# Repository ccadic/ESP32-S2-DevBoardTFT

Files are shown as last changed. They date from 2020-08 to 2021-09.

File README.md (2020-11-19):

# ESP32-S2-DevBoardTFT

BREAKING NEWS !!!!! We started a Crowdsupply campaign because of many requests. You can get a fully assembled product here: https://www.crowdsupply.com/morpheans/morphesp-240
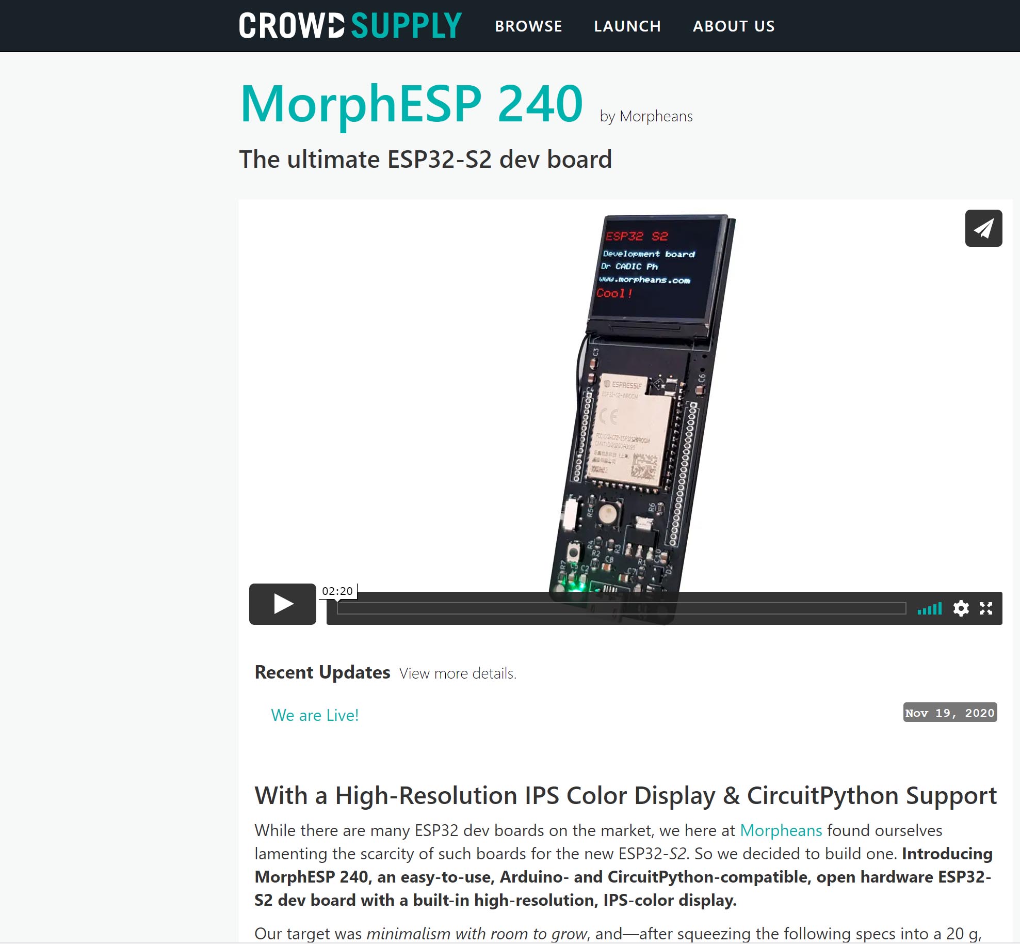
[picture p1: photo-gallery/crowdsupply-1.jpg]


Esp32-S2 dev board with 240x240 IPS display

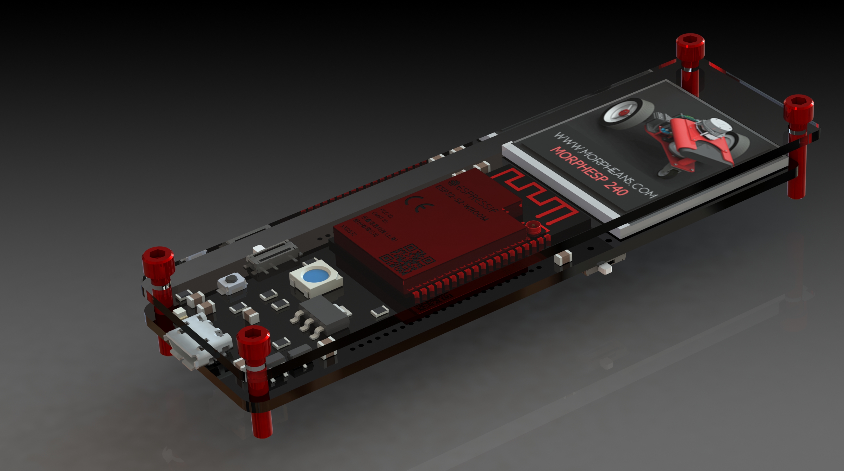
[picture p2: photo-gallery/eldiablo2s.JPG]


A powerfull dev board with the ESPRESSIF™ ESP32-S2®, a high resolution display, a RGB LED, a battery charger and a bunch of GPIOs.

There are many ESP32 board on the market but very few with the new ESP32-S2 which handles USB communications, new cryptography functions. We wanted to have a board with a built in hi-resolution IPS Color Display. After years playing with previous versions of the ESP32, building security devices, text pagers, we just wanted to go one step further and have our opensource circuit.

We wanted to have something minimalistic but expandable so we chose the ESP32 S2 WROOM component , a classic WS2812B RGB LED, a classic 5v to 3.V voltage regulator. 
We wanted something extremely easy to use therefore fully compatible with ARDUINO® IDE plateform.  We also wanted something simple to handle as a first crowdfunding project. 

Features & Specifications

•	Processing:
    o	32-bit esp32 processor operating at 240 MHz
    o	4 MB SPI flash

•	Wireless:
    o	2.4 GHz Wi-Fi - 802.11b/g/n
    o	PCB Antenna

•	Power:
    o	3.3 V LDO regulator
    o	Optimised power path for low-power battery usage
    o	LiPo battery management
    o	Battery pads on the bottom support both JST PH 
    o	Power LEDs

•	Form-factor:
    o	1.27 pinout spacing connector
    o	Breadboard friendly with the dev shield

•	Connectivity:
    o	GPIO broken out to standard pitch headers 1.27 mm
    o	USB + serial/UART for programming
    o	On Board Programmable RGB LED

•	Control:
    o	Arduino IDE compatibility and MicroPython compatibilité
    o	Supports Arduino IDE
    o	Supports Espressif IDF
    o	Thousands of code over the internet

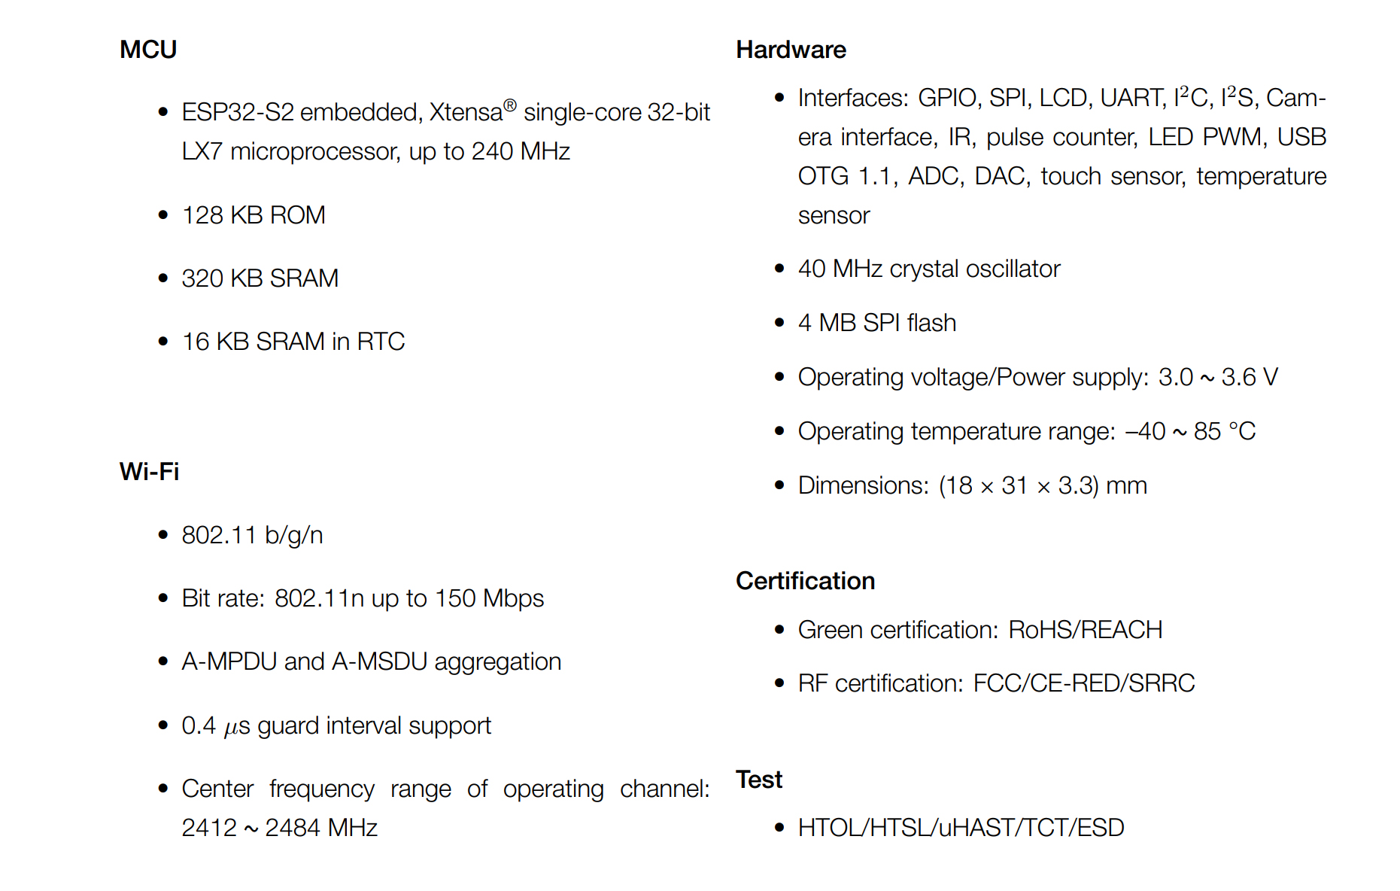
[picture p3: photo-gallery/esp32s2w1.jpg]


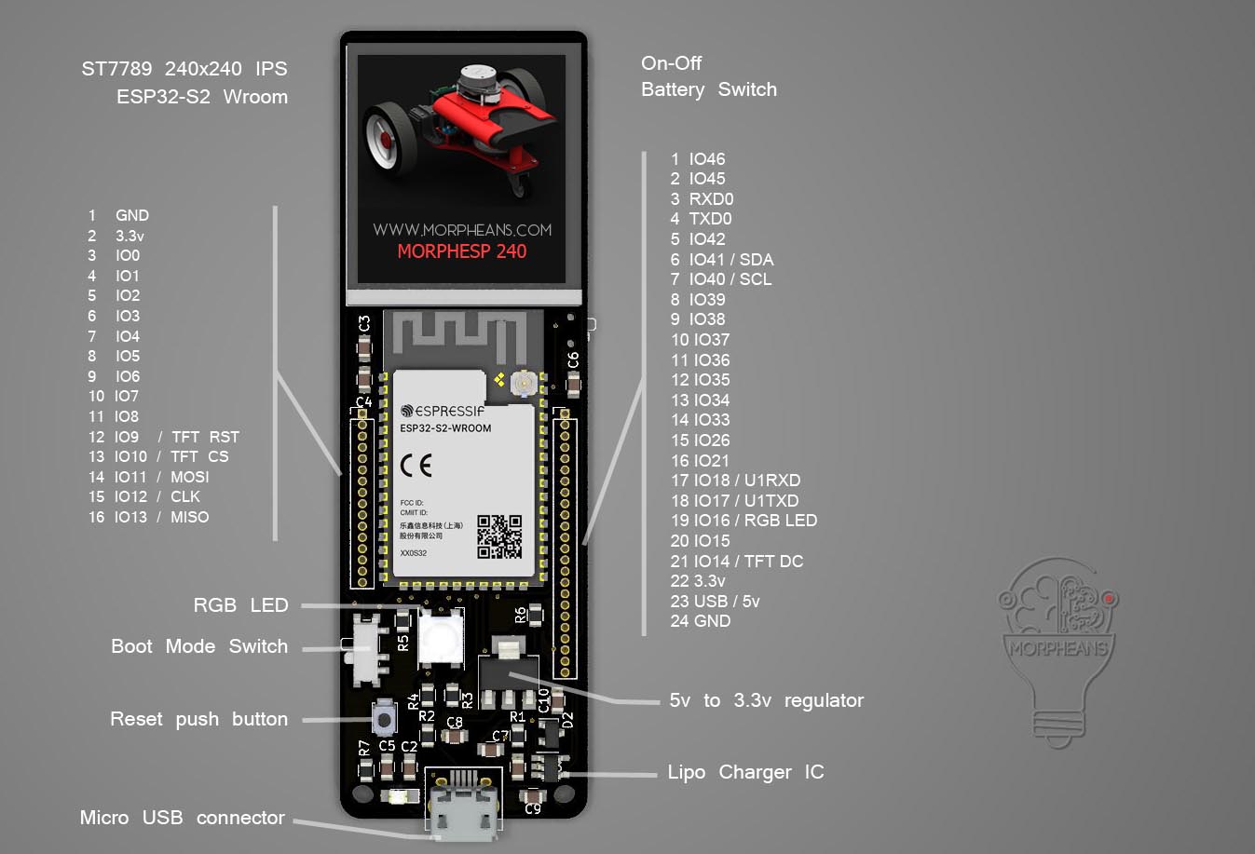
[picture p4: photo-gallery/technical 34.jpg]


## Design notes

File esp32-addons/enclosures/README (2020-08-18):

This dir has all the files if you want to designn, modify or print enclosures for the MORHESP 240
It contains plans, stp, solidworks, STEP files

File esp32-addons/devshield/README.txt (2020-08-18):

(C) 2020 - Dr CADIC Philippe
www.morpheans.com

This is a breadboard friendly development shield for the MORPHESP 240
You get access to all GPIO, grouped connectors (SPI , I2C)...

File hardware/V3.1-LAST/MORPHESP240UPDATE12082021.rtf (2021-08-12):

MORPHESP240
Update

Hi ALL Backers
We would like to thank you all for our first campaign. As this was the first attempt for us, we have learned a lot of things any small team should learn. This was a great experience for the 2 of us.
Almost 90% of you should have received your MORPHESP240 which make us glad. Over the hundreds MORPHESP240 delivered, we have 2 or 4 of you asking for clarification or facing problems (mostly the USB connection and sketch uploads)
The ESP32S2 is new and we chose to have a direct USB connection (morphESP240 does not use a converter such as the CP2104 or CH240G), therefore you need to switch the dev board into boot mode to be able to have it recognized by your ARDUINO IDE interface and OS.
You also have to be careful about the Espressif® Boards Lib you use within ARDUINO IDE. Get sure you have the latest which has the ESP32S2-dev . Please read the READ_FIRST.pdf file you find in the github directory (https://github.com/ccadic/ESP32-S2-DevBoardTFT/tree/master/hardware/V3.1-LAST) . This file gives details on the different steps you have to follow to get a good upload.
We have updated the KICAD sources and schematics. PLease visit : https://github.com/ccadic/ESP32-S2-DevBoardTFT/tree/master/hardware/V3.1-LAST
We also have a couple of requests from Linux users and mac users. The process to upload should not be a lot different byt we admit we have a lower expertise with those systems as the MORPHESP240 has been made and eavily tested under Windows® Please be kind with us if we cannot answer all technical questions about other systems. Most of the time, we ask, and get returns from the linux/mac community of backers who managed. We will regularly update our FAQ should backers raise issues in the future.

Florian & Philippe
Back at work to prepare another fun crowdsupply campaign …. Stay tuned

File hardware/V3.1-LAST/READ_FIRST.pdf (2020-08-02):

ESP32-S2 DEV BOARD , HOW TO START

To upload the sketch you have to select the proper board. See video. https://tutorial.cytron.io/2020/06/25/program-esp32-s2-using-arduino-ide-unofficial/ to understand how to setup arduino IDE. When ARDUINO IDE is set correctly, you can plug the ESP32-S2 dev board to the USB port.

Select the following parameters for the board . You should also select UPLOAD MODE from UART0 to USB CDC

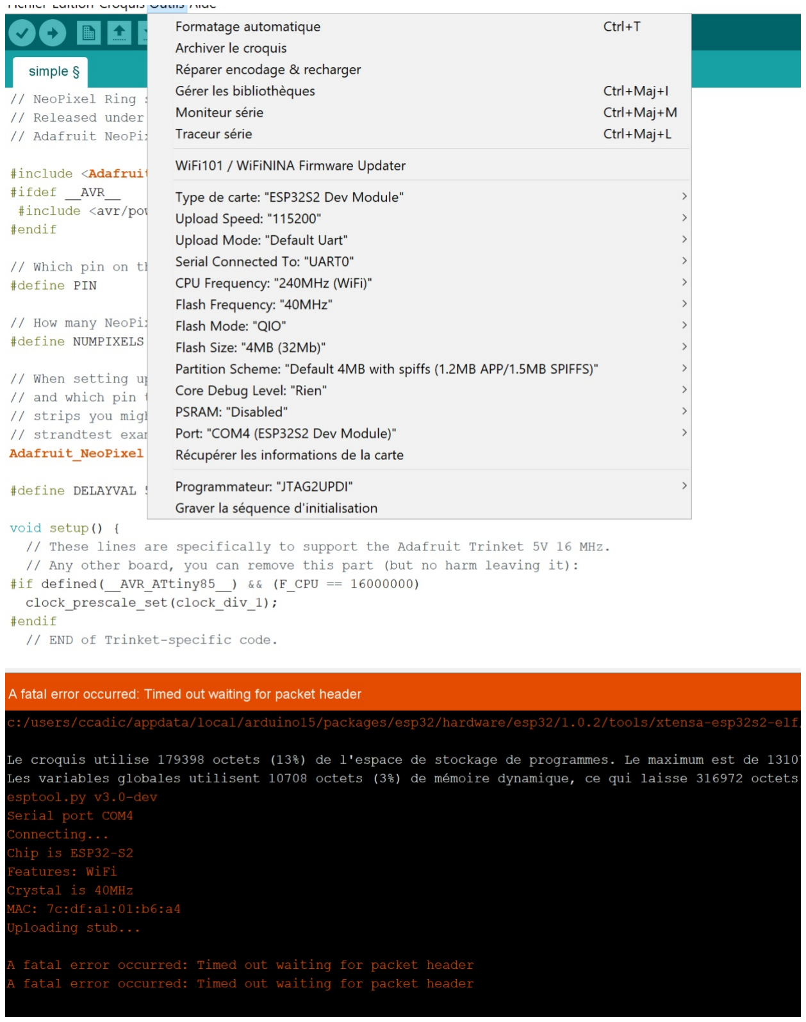
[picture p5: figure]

And select USB UPLOAD MODE to USB CDC

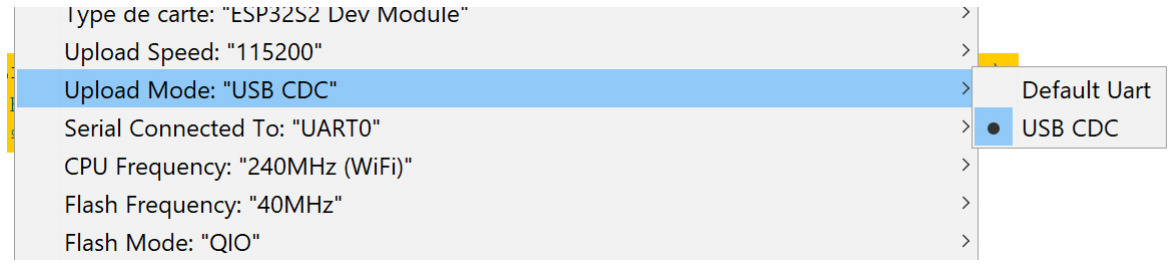
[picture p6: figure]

Put the board in upload mode. For this, put the left button (boot) to the up position and then press the RESET BUTTON (near R7 Resistor). Release the RESET BUTTON and keep BOOT switch in position. The sketch should upload well. Once uploaded , put the BOOT switch to off (Down position) and press RESET again. The ESP32-S2 should now reboot in RUN MODE.

CORRECTION / GERBER 1

The Gerber1 has a small issue you may correct. The TFT DISPLAY RESET has no trace to GPIO12. It is suggested to solder a small wire from PIN 11 of the TFT Display and connect its orther end to GPIO12 of the ESP32 WROOM.

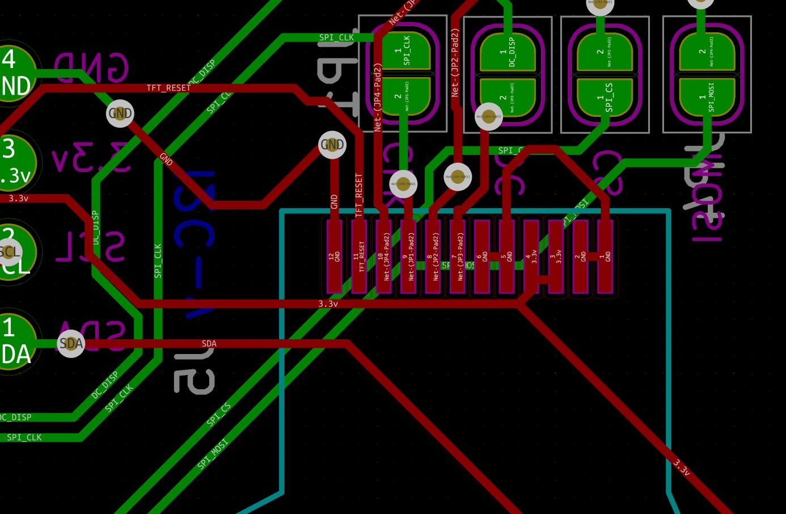
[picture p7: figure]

Gerber 1.2 has corrected this issue.

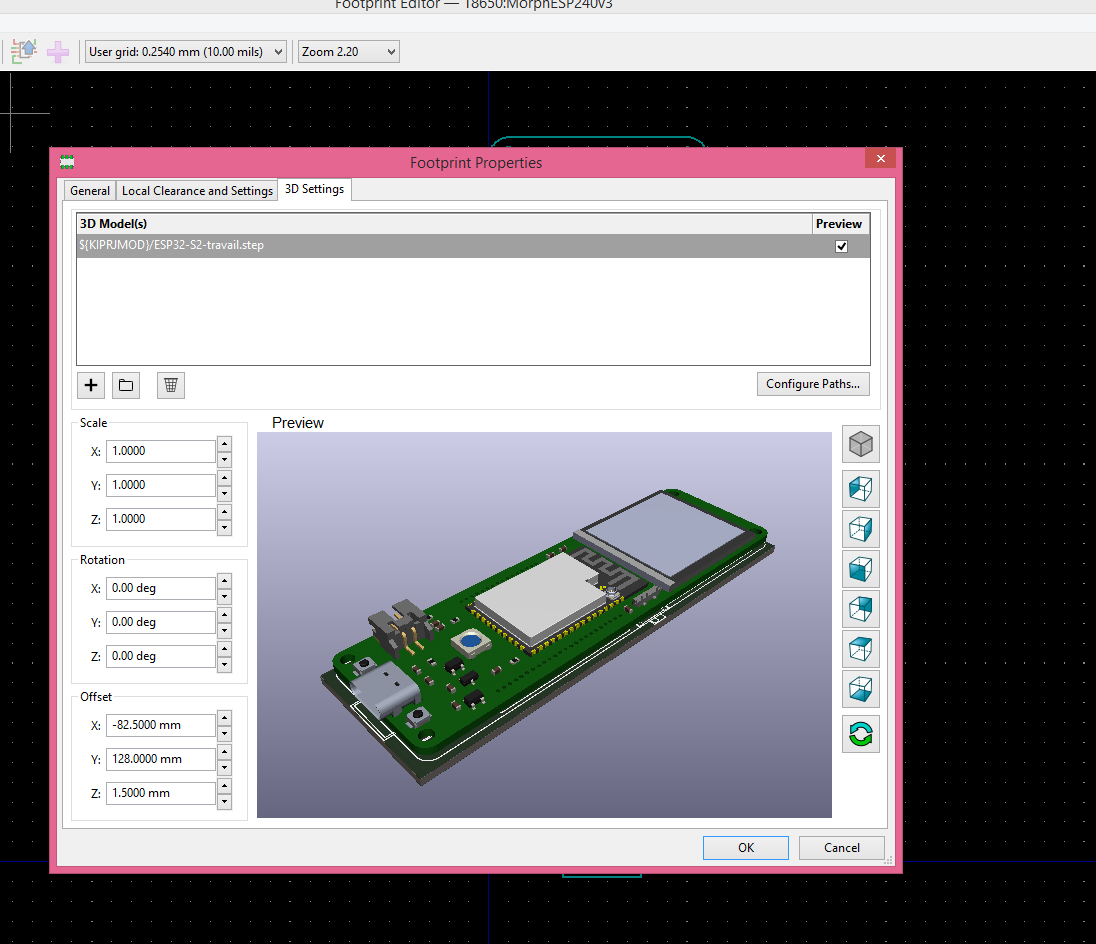
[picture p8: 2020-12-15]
hardware/v3/kicad_footprint/kicad-2.jpg

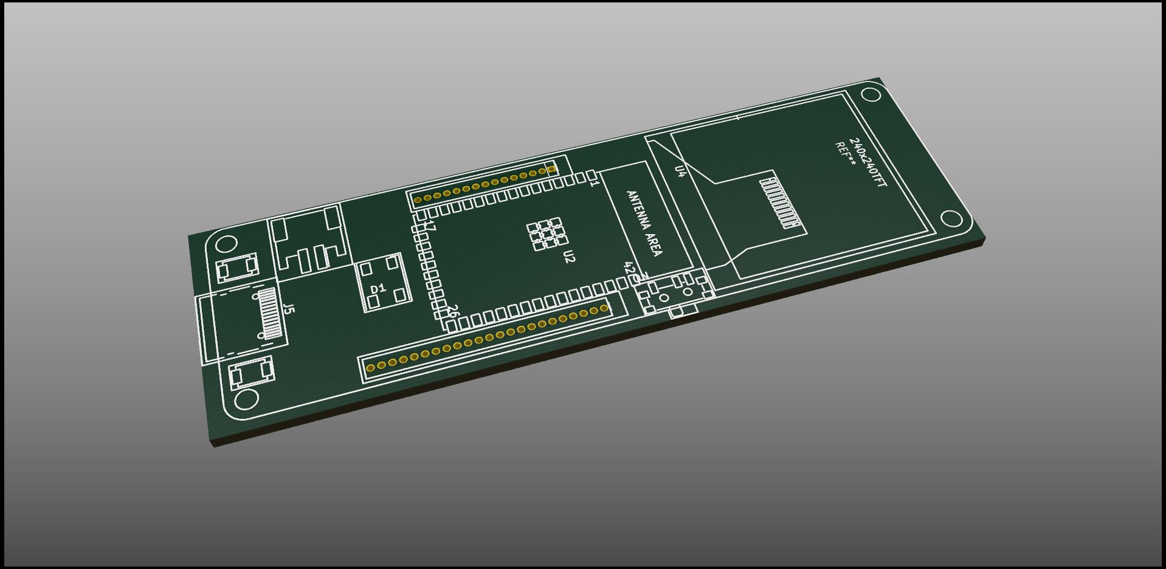
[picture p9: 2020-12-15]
hardware/v3/kicad_footprint/kicadv3fotprint.jpg

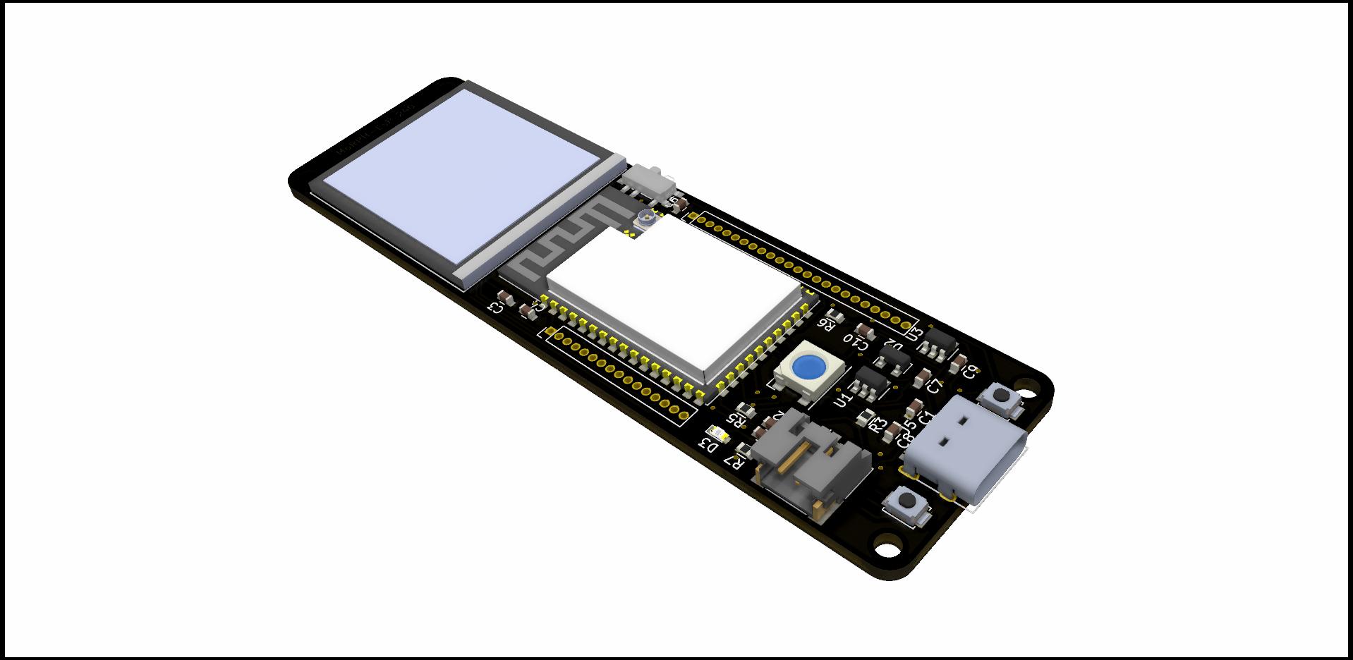
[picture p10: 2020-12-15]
hardware/v3/kicad_footprint/morphESP240v3.jpg

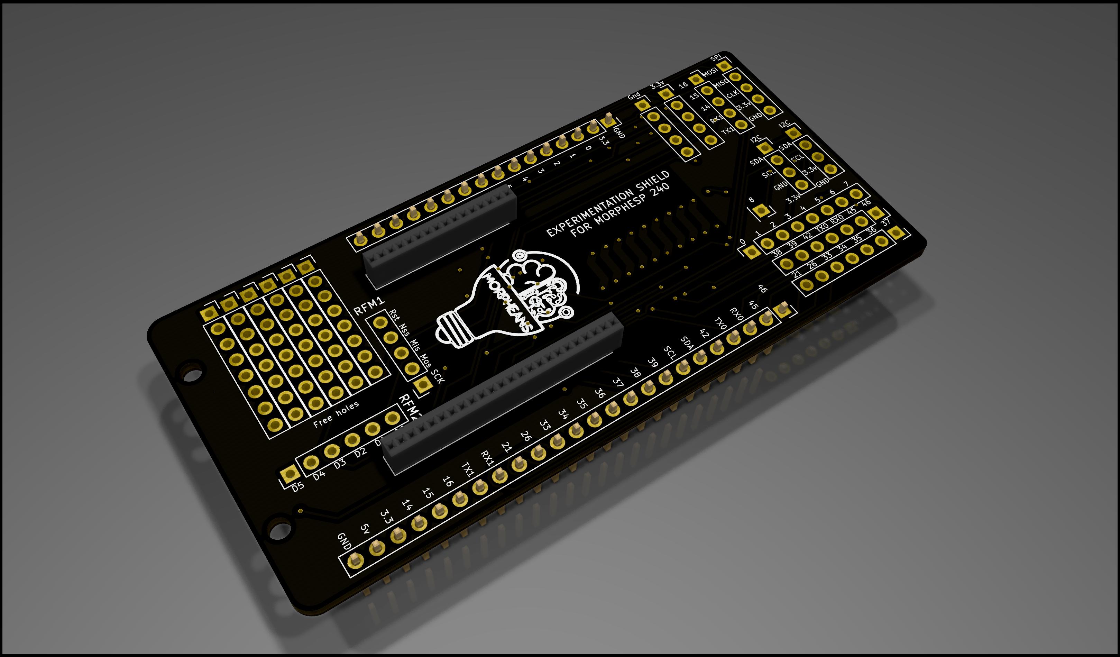
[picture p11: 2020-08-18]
esp32-addons/devshield/images/ESP32-S2-WROOM.jpg

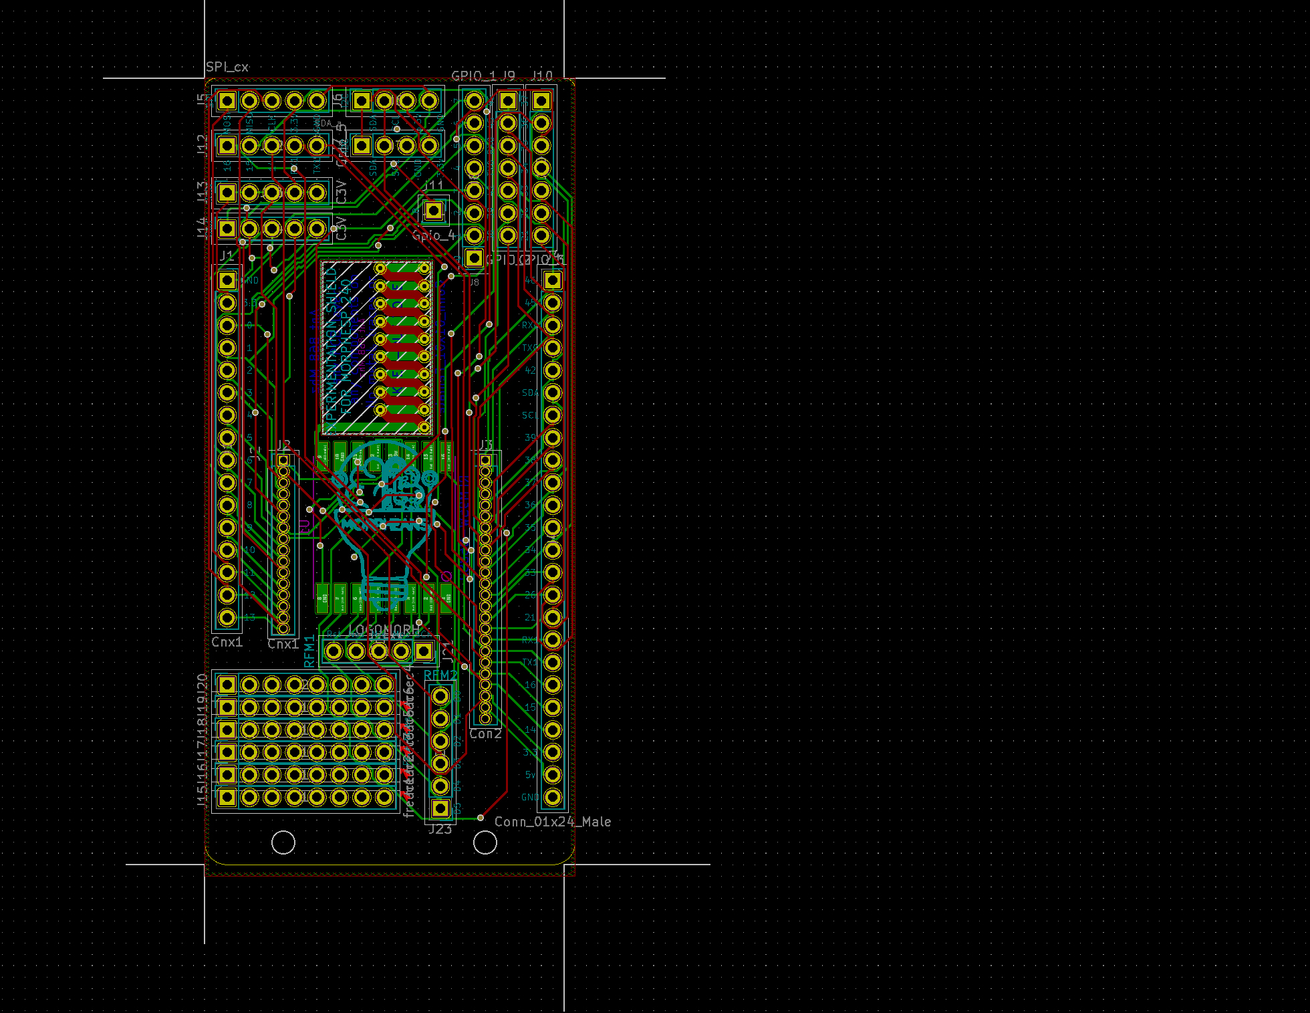
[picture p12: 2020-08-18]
esp32-addons/devshield/images/boardimage.jpg

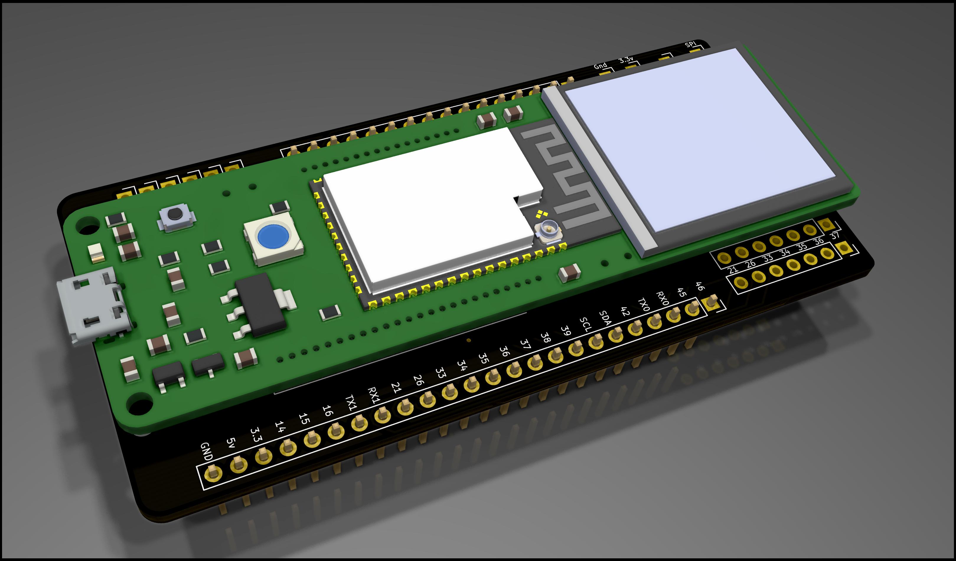
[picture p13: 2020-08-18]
esp32-addons/devshield/images/ESP32-S2-WROOM2.jpg

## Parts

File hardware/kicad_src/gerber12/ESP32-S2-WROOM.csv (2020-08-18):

Id | Référence | Boîtier | Quantité | Désignation | Fournisseur et réf
1 | C1,C2 | C_0805 | 2 | 20pF
2 | C3,C5,C6 | C_0805 | 3 | 100nF
3 | C4,C7,C8 | C_0805 | 3 | 10uF
4 | J1 | USB_Micro-B_HandSoldering | 1 | USB_B_Mini
5 | R1,R2,R4 | R_0805 | 3 | 0R
6 | R3 | R_0805 | 1 | 10k
7 | SW1 | SW_SPST_B3U-1000P | 1 | SW_Push |  | https://www.digikey.fr/product-detail/fr/omron-electronics-inc-emc-div/B3U-1000P/SW1020CT-ND/1534357
8 | SW2 | SW_SPDT_PCM12 | 1 | Boot |  | https://www.digikey.fr/product-detail/fr/c-k/PCM12SMTR/401-2016-1-ND/1640125
9 | U1 | SOT-223-3_TabPin2 | 1 | AP1117-33
10 | U2 | esp32-s2-wrooom | 1 | esp32-s2-wroom |  | https://fr.aliexpress.com/item/4001098252354.html
11 | J2 | Socket_Strip_Straight_1x16_Pitch1.27mm | 0 | Cnx1
12 | J3 | Socket_Strip_Straight_1x24_Pitch1.27mm | 0 | Con2
13 | D1 | LED_WS2812B-PLCC4 | 1 | WS2812B |  | https://fr.aliexpress.com/item/32826552621.html
14 | R5 | R_0805 | 1 | 470
15 | C9,C10 | C_0805 | 2 | 4.7uF
16 | D2 | SOT-23 | 1 | BAT54C |  | https://fr.aliexpress.com/item/4001112729468.html
17 | D3 | LED_0805_HandSoldering | 1 | Charge
18 | J4 | JST_PH_S2B-PH-SM4-TB_02x2.00mm_Angled | 1 | Conn_01x02_Female |  | https://fr.aliexpress.com/item/32806124462.html | 2 PINS JST ANGLED
19 | R6 | R_0805 | 1 | 2k
20 | R7 | R_0805 | 1 | 470R
21 | U3 | SOT-23-5_HandSoldering | 1 | MCP73831-2-OT
22 | U4 | 240240TFT | 1 | 240x240TFT |  | https://fr.aliexpress.com/item/32904333824.html | Attached to PCB with 2 sides adhesive tape
23 | SW3 | SW_SPDT_PCM12 | 1 | ON |  | https://www.digikey.fr/product-detail/fr/c-k/PCM12SMTR/401-2016-1-ND/1640125
 |  |  | 29

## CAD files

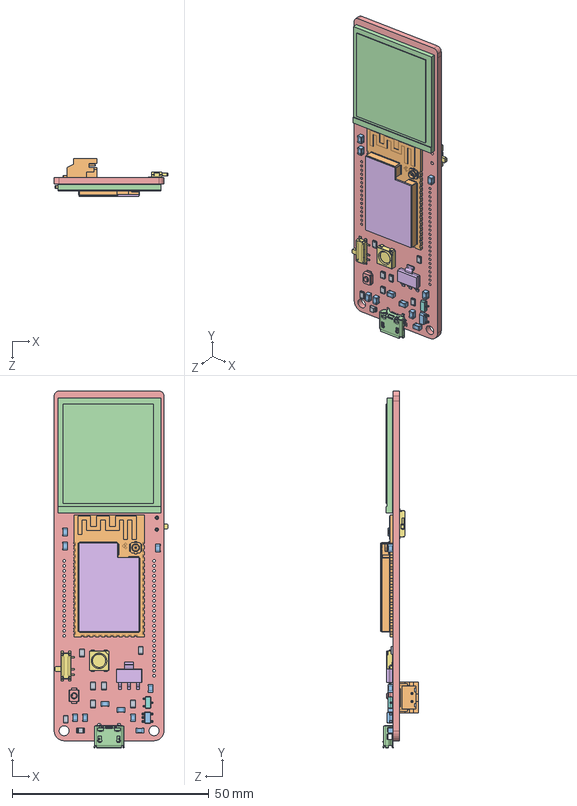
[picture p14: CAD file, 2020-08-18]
esp32-addons/leather-holder/esp32s2-boardonly.SLDASM
28.9 x 90.7 x 9.68 mm
SOLID.step x 7
COMPOUND.step
SOLID-0.step x 10
COMPOUND-1.step
COMPOUND-2.step
SOLID-3.step
SOLID-4.step
SOLID-5.step
SOLID-6.step
COMPOUND-7.step
SOLID-8.step
SOLID-9.step
COMPOUND-10.step
esp32decalk
PCM12SMTR x 2

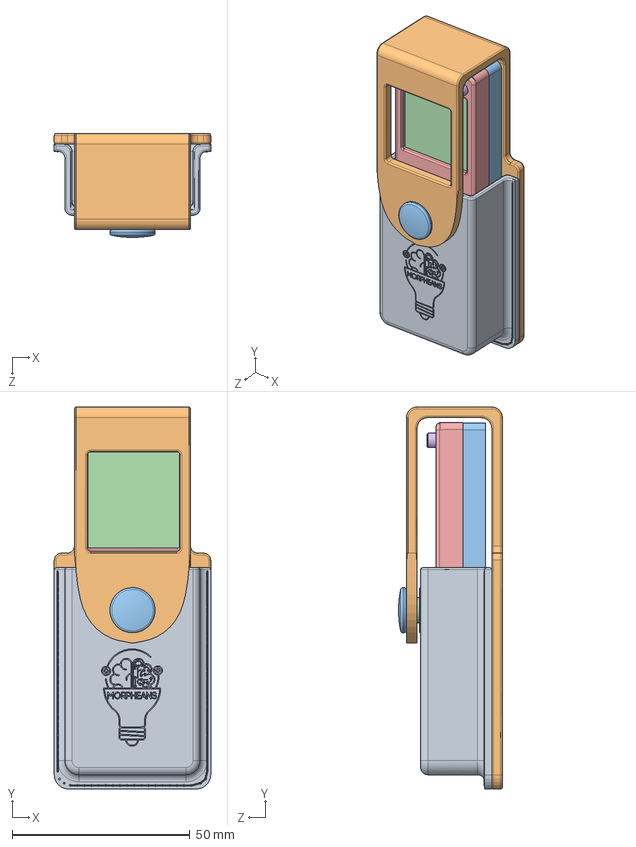
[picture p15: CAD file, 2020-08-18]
esp32-addons/leather-holder/etui_cuir_assemble.SLDASM
44.0 x 107.4 x 29.2 mm
etui
supportcinture
Line 20 Eyelet
Line 20 Stud
SOLID.step x 7
COMPOUND.step
SOLID-0.step x 10
COMPOUND-1.step
COMPOUND-2.step
SOLID-3.step
SOLID-4.step
SOLID-5.step
SOLID-6.step
COMPOUND-7.step
SOLID-8.step
SOLID-9.step
COMPOUND-10.step
PCM12SMTR x 2
coquefront3
frontalacrylic
frontprotect
socket head cap screw_ai x 4
couture x 74
couturecourbe
couture courbe2
couturecourve3
Line 20 Cap

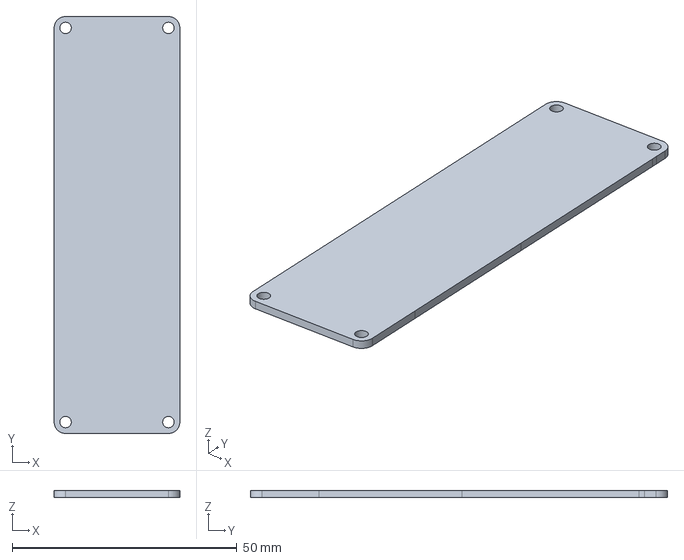
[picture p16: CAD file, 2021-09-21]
acrylic-enclosure/coqueplexy-morphesp240.step
27.9 x 92.7 x 1.60 mm

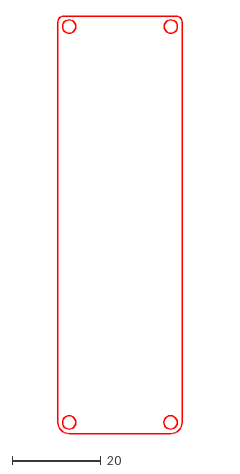
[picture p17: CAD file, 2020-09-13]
esp32-addons/enclosures/lasercutsources/frontalacrylic3mm_holes.DXF
27.9 x 93.9

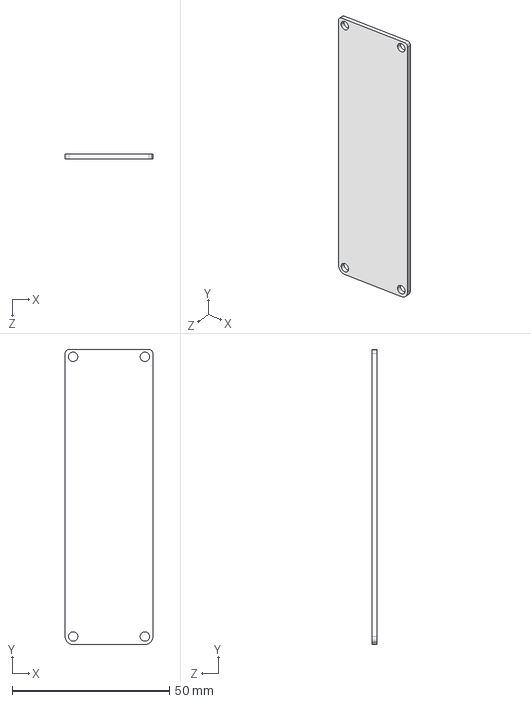
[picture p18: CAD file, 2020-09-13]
esp32-addons/enclosures/step/frontalacrylic3mm_holes.STEP
27.9 x 93.9 x 1.50 mm

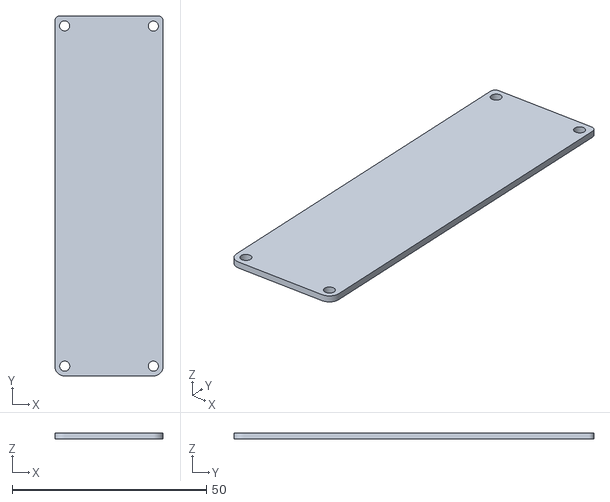
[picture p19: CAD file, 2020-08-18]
esp32-addons/enclosures/stl/morphesp240-plane-covers - frontalacrylic-1.STL
27.9 x 92.7 x 1.50

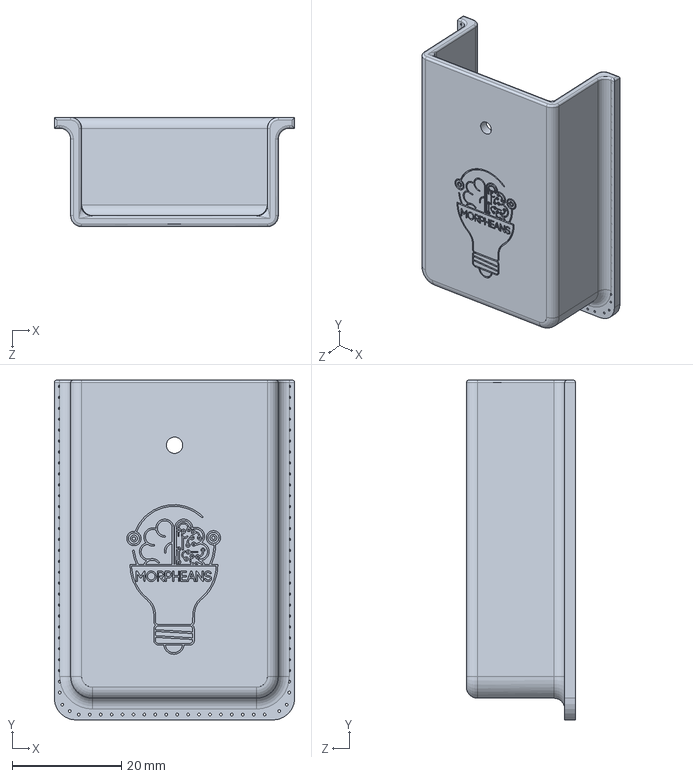
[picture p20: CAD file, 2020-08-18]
esp32-addons/leather-holder/etui.SLDPRT
44.0 x 62.2 x 20.0 mm

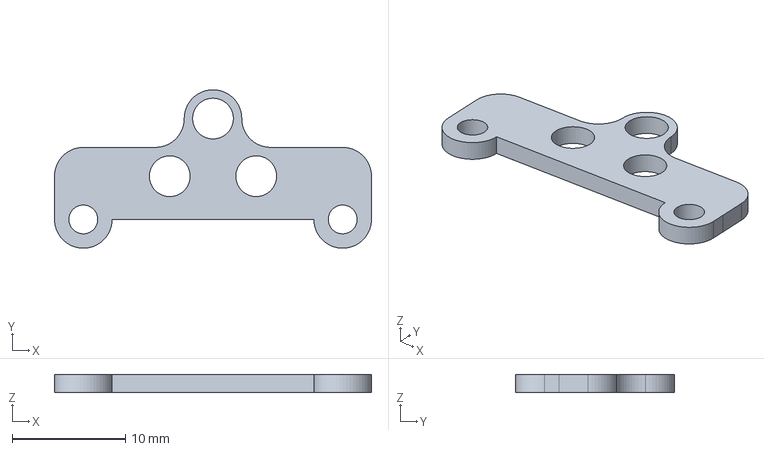
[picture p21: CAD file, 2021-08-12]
hardware/V3.1-LAST/3Dfiles/fixateur_pcb.step
27.9 x 14.0 x 1.60 mm

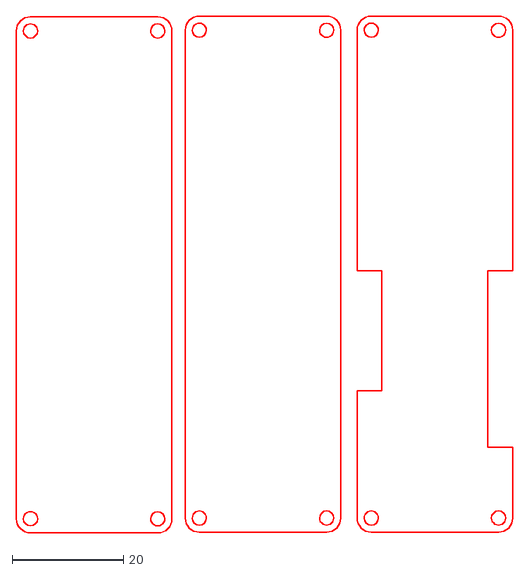
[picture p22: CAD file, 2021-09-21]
MorphESP240-acrylic-layers.dxf
89.2 x 92.8

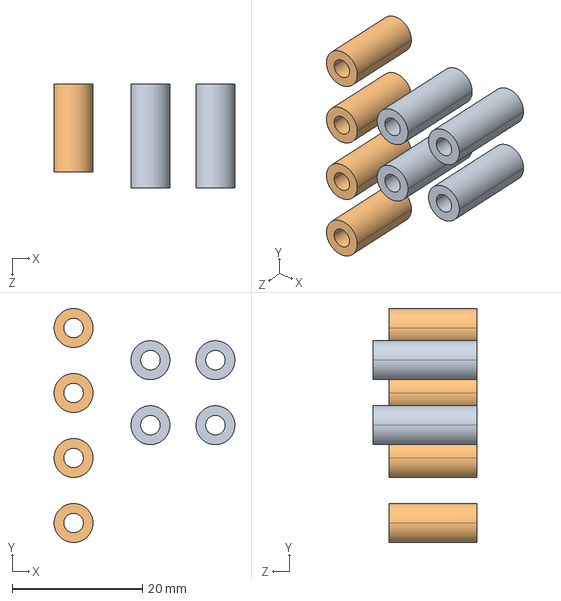
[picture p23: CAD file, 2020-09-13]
esp32-addons/enclosures/step/spacers.STEP
27.8 x 36.0 x 16.0 mm

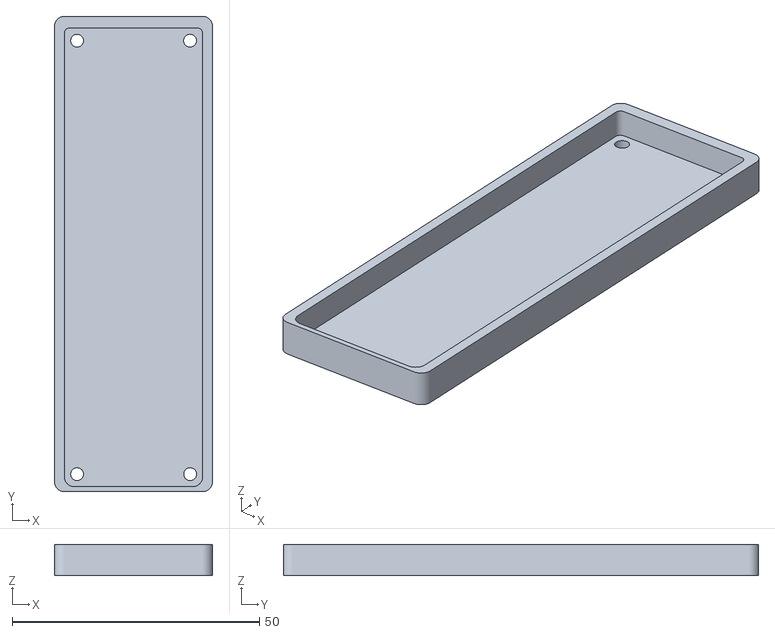
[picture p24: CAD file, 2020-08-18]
esp32-addons/enclosures/stl/wrap-enclosure - lowerenclosure-1.STL
31.9 x 96.1 x 6.35

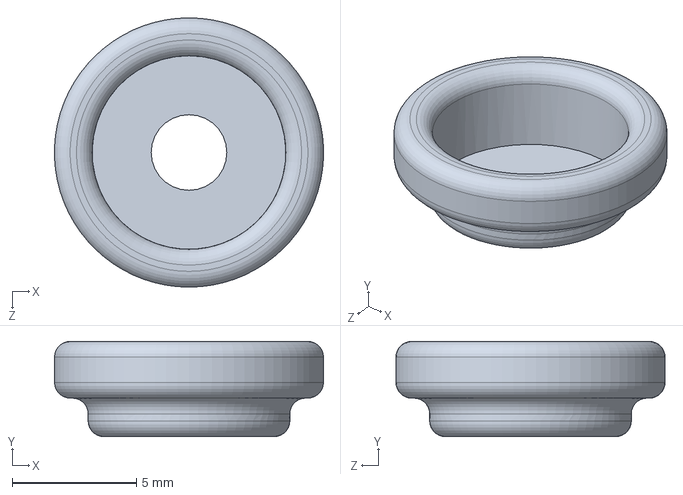
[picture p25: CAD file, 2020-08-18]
esp32-addons/leather-holder/Line 20 Socket.SLDPRT
10.8 x 3.84 x 10.8 mm

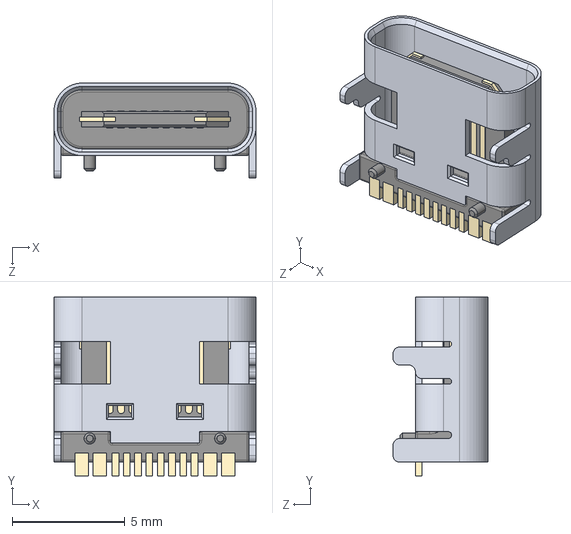
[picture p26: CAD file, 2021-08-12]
hardware/V3.1-LAST/3Dfiles/USB Type C Port (SMD Type).STEP
8.94 x 7.90 x 4.20 mm

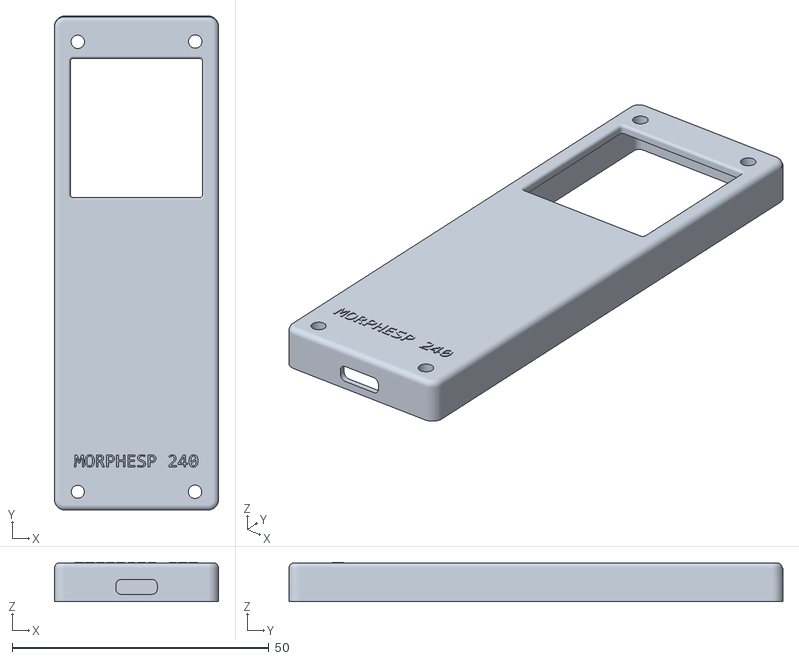
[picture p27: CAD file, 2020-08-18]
esp32-addons/enclosures/stl/wrap-enclosure - frontprotect-3.STL
31.9 x 96.1 x 7.65

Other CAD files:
esp32-addons/leather-holder/etuit.SLDPRT
hardware/V3.1-LAST/3Dfiles/lipobat.STEP
esp32-addons/enclosures/stl/morphesp240-plane-covers - coquefront3-1.STL
esp32-addons/leather-holder/Line 20 Eyelet.SLDPRT
esp32-addons/enclosures/solidworks/frontalacrylic3mm_holes.SLDPRT
esp32-addons/enclosures/solidworks/spacers.SLDPRT
esp32-addons/enclosures/stl/frontalacrylic3mm_holes.STL
esp32-addons/enclosures/stl/spacers.STL
esp32-addons/leather-holder/Line 20 Cap.SLDPRT
esp32-addons/leather-holder/Line 20 Stud.SLDPRT
esp32-addons/leather-holder/couture courbe2.SLDPRT
esp32-addons/leather-holder/couture.SLDPRT
esp32-addons/leather-holder/couturecourbe.SLDPRT
esp32-addons/leather-holder/couturecourve3.SLDPRT
esp32-addons/leather-holder/etui_cuir_assemble.SLDDRW
esp32-addons/leather-holder/supportcinture.SLDPRT
hardware/V3.1-LAST/3Dfiles/240240TFT.STEP
hardware/V3.1-LAST/3Dfiles/B3U1000P.step
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

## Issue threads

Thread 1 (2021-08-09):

USB doesn't properly enumerate

davidgs, 2021-08-09:
Plug the MORPEsp32 in to USB and ...

```
 % ls -l /dev/*usb*
crw-rw-rw-  1 root  wheel    9,   5 Aug  9 17:45 /dev/cu.usbmodem01
crw-rw-rw-  1 root  wheel    9,   4 Aug  9 17:45 /dev/tty.usbmodem01
%
```
But those are not ports that esptool can work with.

```
esptool.py v3.0-dev
Serial port /dev/cu.usbmodem01
Connecting....Traceback (most recent call last):
  File "esptool.py", line 3969, in <module>

  File "esptool.py", line 3962, in _main
  File "esptool.py", line 3552, in main
  File "esptool.py", line 519, in connect
  File "esptool.py", line 499, in _connect_attempt
  File "esptool.py", line 438, in sync
  File "esptool.py", line 402, in command
  File "serial/serialutil.py", line 368, in timeout
  File "serial/serialposix.py", line 326, in _reconfigure_port
serial.serialutil.SerialException: Could not configure port: (6, 'Device not configured')
Failed to execute script esptool
An error occurred while uploading the sketch
```

Also, not having a board definition available for Arduino makes programming this board rather hard. Any plans to actually support this board properly?

ccadic, 2021-08-10:
Hi. It s philippe.  Hope I can help you.0
Florian has send me the information. I am out of any linux computer until the end of my vacation (august the 23rd)
The board was mainly tested with windows and mac. We are not experts with linux and HID/USB linux recognition. Which linux distribution ? Which version ? Which kerbel version ? Any usb modification to the kernel ? Which arduino IDE for linux version ? Any update with the ESP32s2 card package ? Which one ?  I can then install the same dzv environment when back.

What to you mean by "board definition" ? Can you point me to an example of such document . Maybe I call it something else.  As the boarf is recognized with no issue we probably did no dig in this direction

With windows and mac it is sometimes requested to press the reset/boot buttons to switch the mprphesp240 to sketch upload mode (on windows, there is a sound to confirm the switch from one mode to the other. Then we can select the COM port in arduino IDE).  Maybe it is necessary to do the same with linux.

I trying to get return from the community from backers who are using the board with linux. And find a way to help.

ccadic, 2021-08-10:
We already have some returns.
When it is connected on usb a "sudo dmesg" gives the necessary information..

ccadic, 2021-08-10:
To flash :  press left button  - press/release right button / release left button

ccadic, 2021-08-10:
With Kernel 5.13.9

davidgs, 2021-08-10:
I'm not on a Linux box, but a Mac.

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

This is a typical board-manager package that defines a board. https://github.com/sparkfun/Arduino_Boards/tree/main/IDE_Board_Manager

It defines the pinouts, etc. that are specific to this board. For instance, if you look into this one: https://github.com/sparkfun/Arduino_Boards/blob/main/IDE_Board_Manager/sparkfun-esp32-1.0.0.tar.bz2 You will see the various definitions.

It would be super helpful to, for instance, know which pin runs the onboard try-color LED, etc. With essentially no documentation whatsoever -- other than the hardware parts -- it makes developing anything on the board really difficult. Especially so since there are no silkscreen labels on the board for which pins are pulled out where.

Thanks!
dg
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

--
David G. Simmons
(919) 534-5099
Web <https://davidgs.com/>  • Linkedin <https://linkedin.com/in/davidgsimmons> • Twitter <https://twitter.com/davidgsIoT> • GitHub <https://github.com/davidgs> • npx davidgs • Notist <https://noti.st/davidgs> • Book a meeting <https://calendly.com/davidgsimmons/30min>
/** Message digitally signed for security and authenticity.
 * Public key available at https://keys.openpgp.org/
**/
♺ This email uses 100% recycled electrons. Don't blow it by printing!
There are only 2 hard things in computer science: Cache invalidation, naming things, and off-by-one errors.

morpheans, 2021-08-12:
Hi,
Take contact with this man :
https://twitter.com/4hackrr?s=21

He works on Mac, and already parameter the MorphEsp 240 with MacOS.

daviddata1, 2021-08-13:
When I put the board into boot mode, it doesn't mount the USB on a Win 10 machine.  I get the yellow diamond with the exclaimation point inside it in the Device Manager.

Says ESP32-S2 for the device name

Code 28, the drivers for this device are not installed.

When I try to update them, they're not found.

Any ideas?

daviddata1, 2021-08-13:
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

Got it figured out through much GoogleFu and experimentation.

Here's the overview:

1) Attach to USB, Put the board into download mode.  Hold down left push button, Press and hold right button, release right button after a sec or two, release left button...

2) Get the zadig driver tool from https://zadig.akeo.ie

Download version 2.5

Run it.  Install the drivers (USB ID was: 303a 0002).  It'll pause for a few seconds - it's not hung up.  Wait.  It'll start downloading and installing the drivers.... takes a while (I did this on an HP laptop w/an i7 CPU 4GHz, 16GB RAM, 512GB SSD).

3) Drivers install.  Check "Device Manager" in control panel.  You'll no longer see the ESP32-S2 in the "Other Devices" section, it'll show up in the USB Devices section...

I dumped the firmware to a file before fooling with other sketches.

dfu-util -v -U MorphESP240_OriginalDFU.bin

The first time I ran it, it threw an error about being in runtime mode and detaching.

I ran it again, and it worked the 2nd time.  Copied 4194304 bytes...

dfu-util is available at: https://dfu-util.sourceforge.net/releases

I used the dfu-util-0.9-win64.zip

More info at:

https://docs.espressif.com/projects/esp-idf/zn_CN/latest/esp32s2/api-guides/dfu.html

[some of it's in chinese, but you should be able to make it out... break out Google Translate if you need to]

Hope this helps save someone some time...  For a device that's supposedly out in "Production" this should have already been documented.  No, I'm not opposed to hacking or playing with things, but when I buy something I'd like to know if it's "Beta" beforehand in case I just need it to work.  Because I needed this for a particular use case and wasn't sure it was going to actually work, I purchased an m5Stack Core2 from a vendor in the UK, it showed up in the US in a few days, and I had it working immediately.  As a gentle suggestion, if you want to have another successful crowd campaign, please do a better job of documenting.

Note also that the board is a different revision than what you see in the 3D renderings on the website and Crowdsupply.  The battery switch is relocated to the lower-right of the screen, and there's two push buttons on the bottom on either side of the USB connector (left, by the battery connector for RESET), and right (BOOTLOADER)...

morpheans, 2021-08-13:
Esp32 S2 chip does NOT require a specific USB driver. It is native. The ESP32 normal requires one. Not the S2. The trick is to put the morphesp240 into boot mode (see readme first pdf in our github). The way to do this is a bit hard at first time for esp32classic owners. If you have windows, there should be a sound whe the usb port is mounted. Once mounted, recheck the COM port in ArduinoIDE and upload. Get sure your arduino ESp32 boards is up to date and select ESP32-Dev board

Respectueusement

Florian Lecoeuvre
Gérant / Co-Fondateur
SARL Morpheans

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

daviddata1, 2021-08-14:
Thanks for the reply.  I did try without installing any drivers.  Win 10
would say it was setting up the device, then claim it'd set it up, but
it wasn't showing up as a USB device.  It'd show up in the Device
Manager as an "Other Devices" with the warning triangle next to it and
said no drivers were loaded...

Once I took a look at the docs.espressif.com... page I linked
previously, it had a link for a driver at zadig.akeo.ie

Before I had the driver installed, I couldn't dump the firmware with the
dfu-util.  Once I had that driver installed, I could.

Note that I still can't read all 4MB of the SPI Flash with esptool -
won't work unless I have the --no-stub option enabled, and it fails at
50% complete regardless of the baud rate that's set.

I want to get a dump of the original firmware in case something goes
wrong with the sketch upload from the IDE.

Best Regards,

-- David

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

davidgs, 2021-08-14:
Seems to be a moot point now as board number 1 will no longer power on at all, and board number 2 is DOA.

¯\_(ツ)_/¯

morpheans, 2021-08-16:
Embarrassing situation ...
Do you think this is due to the material?

daviddata1, 2021-08-17:
I suspect there's something wrong with this board.  Also, the LED screen overlay seems to have separated from the backlight - glue went bad or something...

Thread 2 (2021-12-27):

No boot switch on USB-C version

TechTactical, 2021-12-27:
I am trying to flash the USB-C version but there is no boot switch. The board is not recognized by my Mac. There's some sort of JST connector where the documentation says a boot switch should be.  Is there updated documentation for this version?  I am flashing via arduino IDE on Mac OSX 10.15.

ccadic, 2021-12-27:
We faced some issues with macs
All of them coming from a faulty or none compatible usb cable. Replacement
solved the issue.

Le lun. 27 déc. 2021 à 18:50, TechTactical ***@***.***> a
écrit :

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

TechTactical, 2021-12-27:
I have the usb-c version of the board.  There is no boot switch.  How do I flash this version?  Is there documentation?

ccadic, 2021-12-27:
can you post a photo ?

Le lun. 27 déc. 2021 à 19:27, TechTactical ***@***.***> a
écrit :

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

--
** Dr Philippe Cadic **
Ce message ainsi que toutes les pièces jointes (ci-après le message) sont
établis à l’intention exclusive de son ou ses destinataires. Si vous
recevez ce message par erreur, merci de le détruire et d’en avertir
immédiatement l’expéditeur par courriel.
Toute utilisation de l’adresse électronique de l’émetteur à des fins
publicitaires, toute utilisation de ce message à des fins non conformes à
sa destination, toute diffusion ou toute publication, totale ou partielle,
est interdite, sauf autorisation expresse.
Les communications sur Internet n’étant pas sécurisées, l'auteur décline
toute responsabilité en cas de modification du message et de ses pièces
jointes.

TechTactical, 2021-12-27:
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

ccadic, 2021-12-27:
the boot and reset switch are marked in yellow.
you have to press them both until the MAC/PC recognize the usb port

YOurs

Le lun. 27 déc. 2021 à 21:53, TechTactical ***@***.***> a
écrit :

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

--
** Dr Philippe Cadic **
Ce message ainsi que toutes les pièces jointes (ci-après le message) sont
établis à l’intention exclusive de son ou ses destinataires. Si vous
recevez ce message par erreur, merci de le détruire et d’en avertir
immédiatement l’expéditeur par courriel.
Toute utilisation de l’adresse électronique de l’émetteur à des fins
publicitaires, toute utilisation de ce message à des fins non conformes à
sa destination, toute diffusion ou toute publication, totale ou partielle,
est interdite, sauf autorisation expresse.
Les communications sur Internet n’étant pas sécurisées, l'auteur décline
toute responsabilité en cas de modification du message et de ses pièces
jointes.

TechTactical, 2021-12-28:
can you post a photo?

TechTactical, 2021-12-28:
Also can you post the demo code that came on the board?  Thank you!

TechTactical, 2021-12-28:
I got the board to show up as a serial connection using the following steps:

In the orientation shown in the photos above (screen on top):

- Press and hold the right button
- Press and hold the left button (2 secs)
- Release the left button
- Release the right button

I will start another issue to request the sample code.

Closed 2021-12-28.

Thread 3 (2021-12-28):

Demo code?

TechTactical, 2021-12-28:
Will you please post the example code that's shipped with the USB-C variant?  The ST7789 display code example in this GitHub repo is not working on my board.  Do you have the pin out diagram for this new version?

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

TechTactical, 2021-12-28:
Can you confirm these parameters?

` #define TFT_DC         14
  #define TFT_RST        9
  #define TFT_CS         10
  #define TFT_MOSI       11
  #define TFT_SCLK       12
`

TechTactical, 2021-12-28:
I am working on new example code that will drive the USB-C revision.  Any code samples you can provide would be helpful.  The code you shipped these with worked well.

TechTactical, 2021-12-28:
Very responsive on the Discord, thank you!

Closed 2021-12-28.

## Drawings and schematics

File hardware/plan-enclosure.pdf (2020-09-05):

E E
9,68

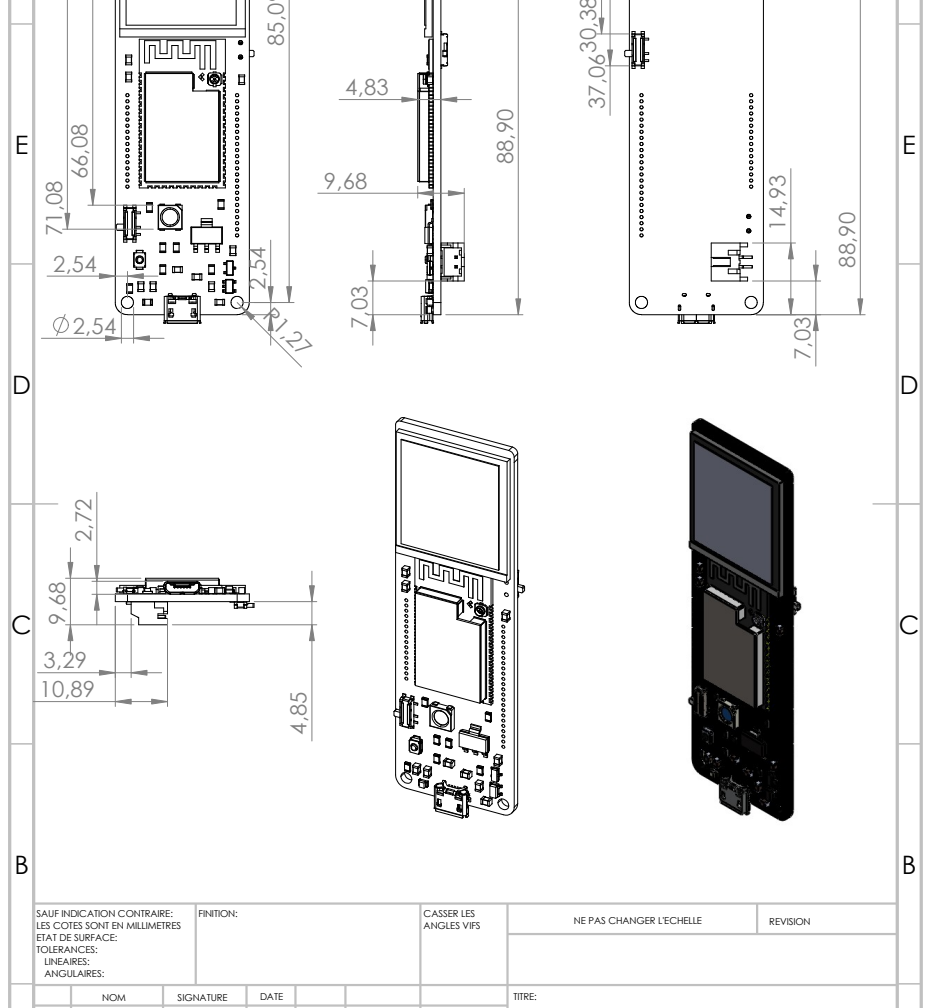
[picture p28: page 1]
TITRE:; FINITION:; ANGLES VIFS; NOM; SIGNATURE; DATE; NE PAS CHANGER L'ECHELLE; REVISION; CASSER LES 9,68 2,72

SAUF INDICATION CONTRAIRE:
LES COTES SONT EN MILLIMETRES
ETAT DE SURFACE:
TOLERANCES:
LINEAIRES:
ANGULAIRES:

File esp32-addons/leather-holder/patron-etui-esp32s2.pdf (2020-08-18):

E E

F F

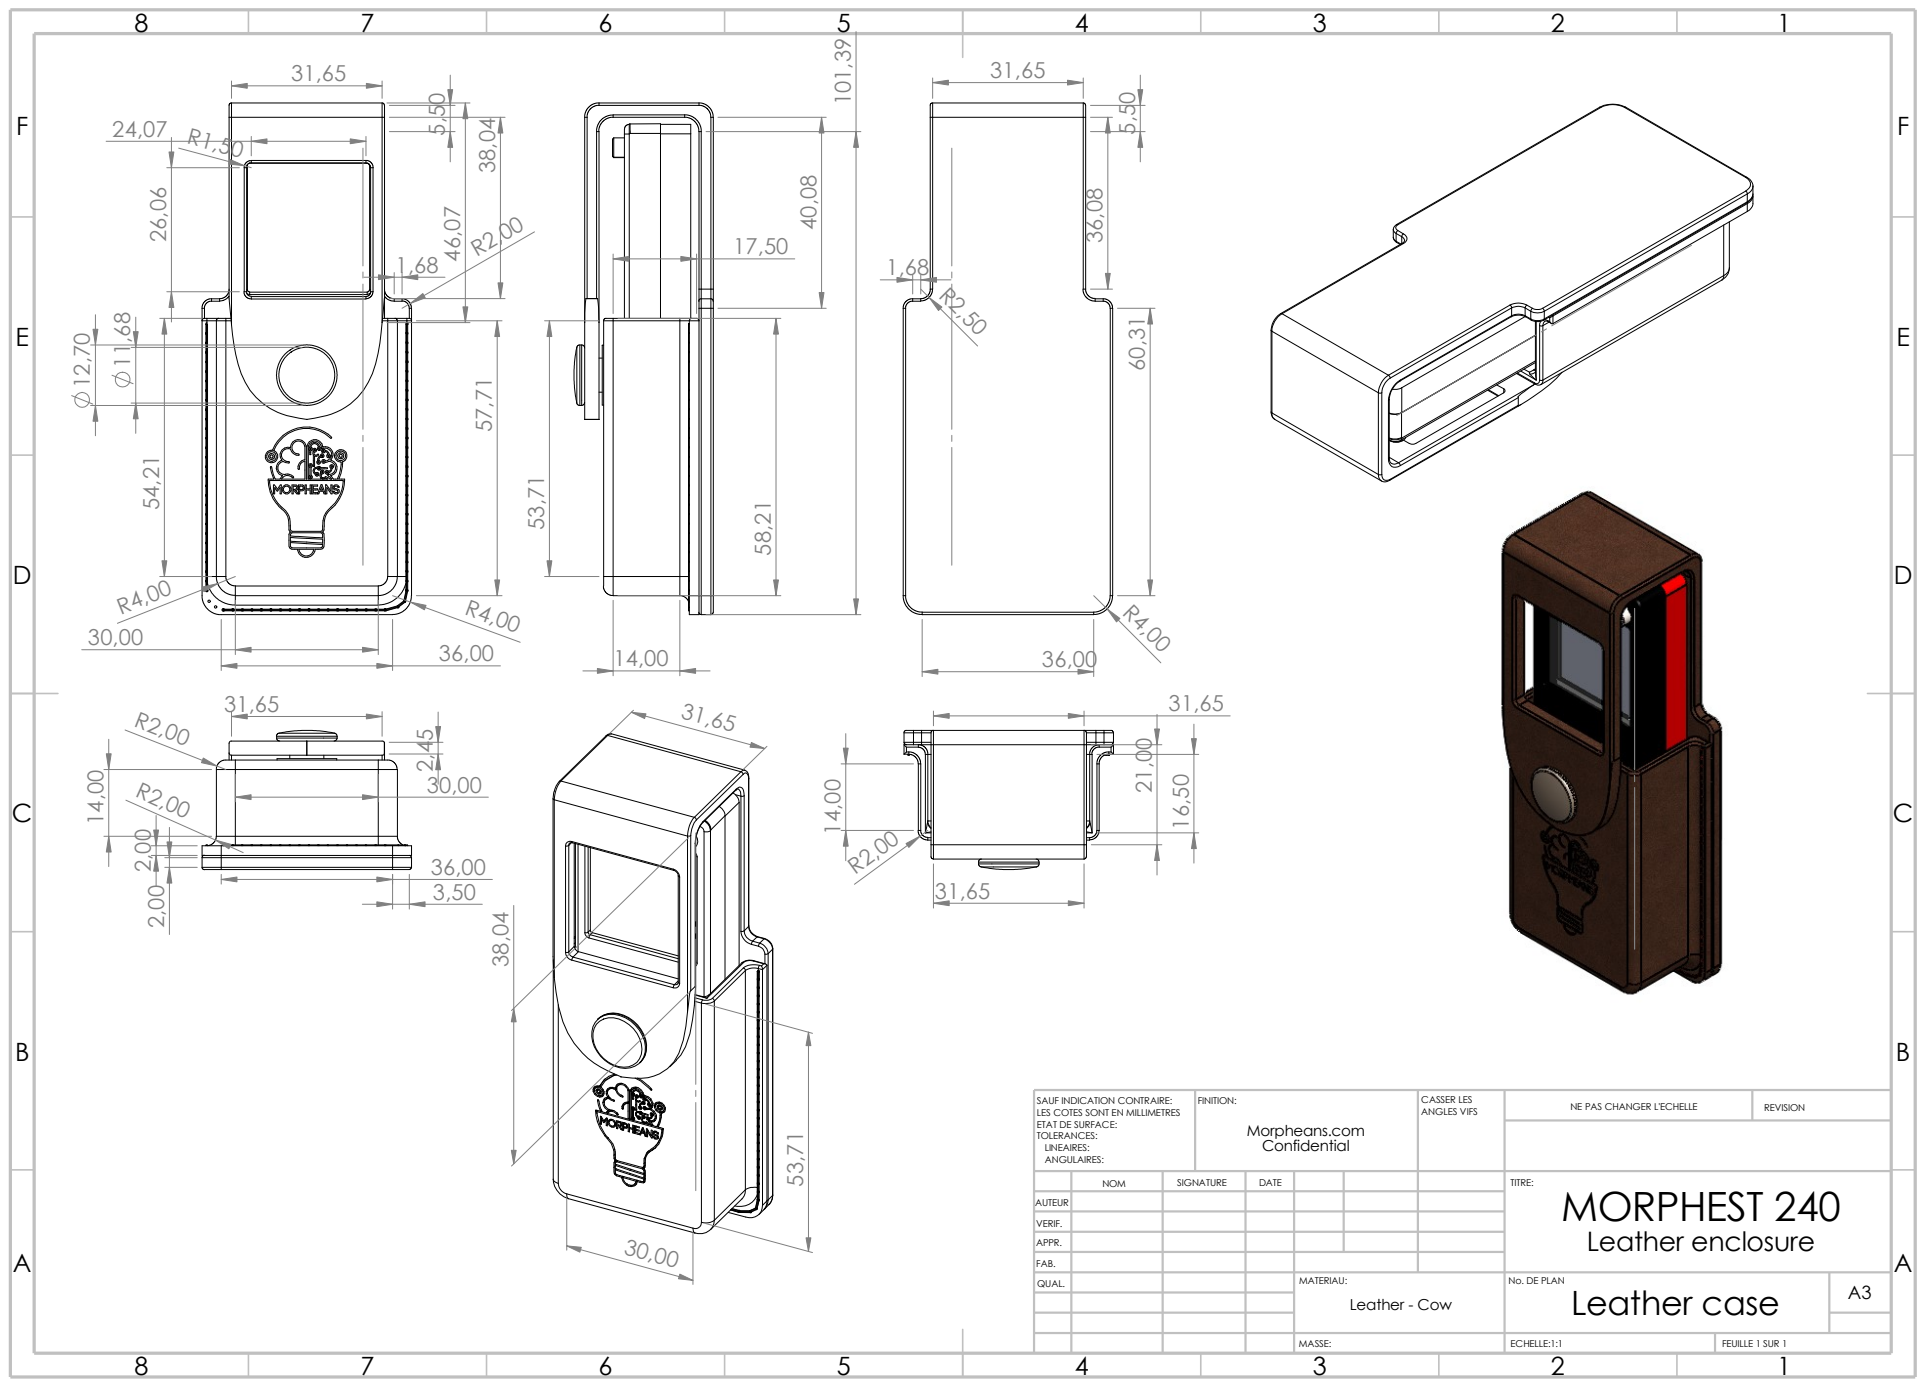
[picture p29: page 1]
ECHELLE:1:1; FEUILLE 1 SUR 1; Confidential; REVISION; FINITION:; CASSER LES; Morpheans.com; MASSE:; ANGLES VIFS

Leather enclosure ³⁶,08

NE PAS CHANGER L'ECHELLE SAUF INDICATION CONTRAIRE:
LES COTES SONT EN MILLIMETRES
ETAT DE SURFACE:
TOLERANCES:
LINEAIRES:
ANGULAIRES:

NOM | SIGNATURE | DATE | | | | TITRE: MORPHEST 240

AUTEUR
VERIF.
APPR.
QUAL. | | | | MATERIAU: Leather - Cow | No. DE PLAN Leather case | A3

FAB.

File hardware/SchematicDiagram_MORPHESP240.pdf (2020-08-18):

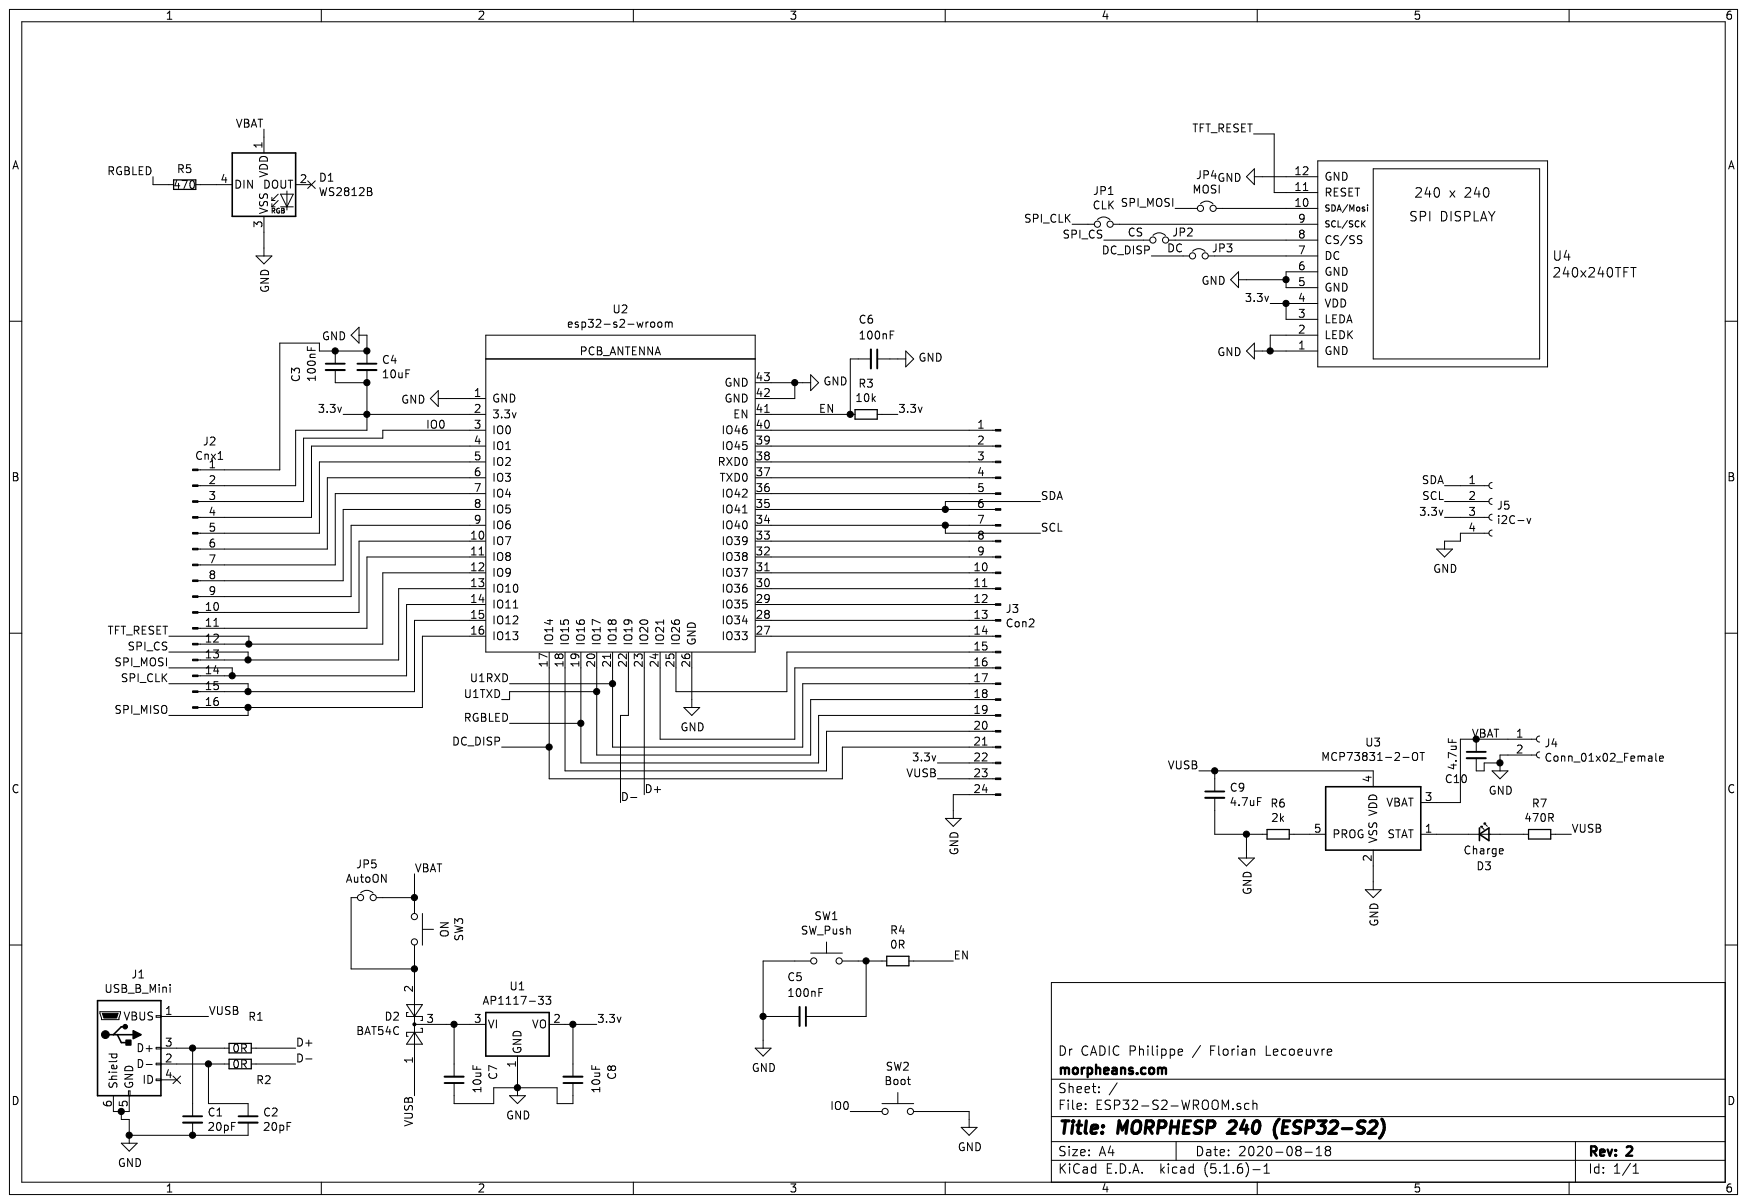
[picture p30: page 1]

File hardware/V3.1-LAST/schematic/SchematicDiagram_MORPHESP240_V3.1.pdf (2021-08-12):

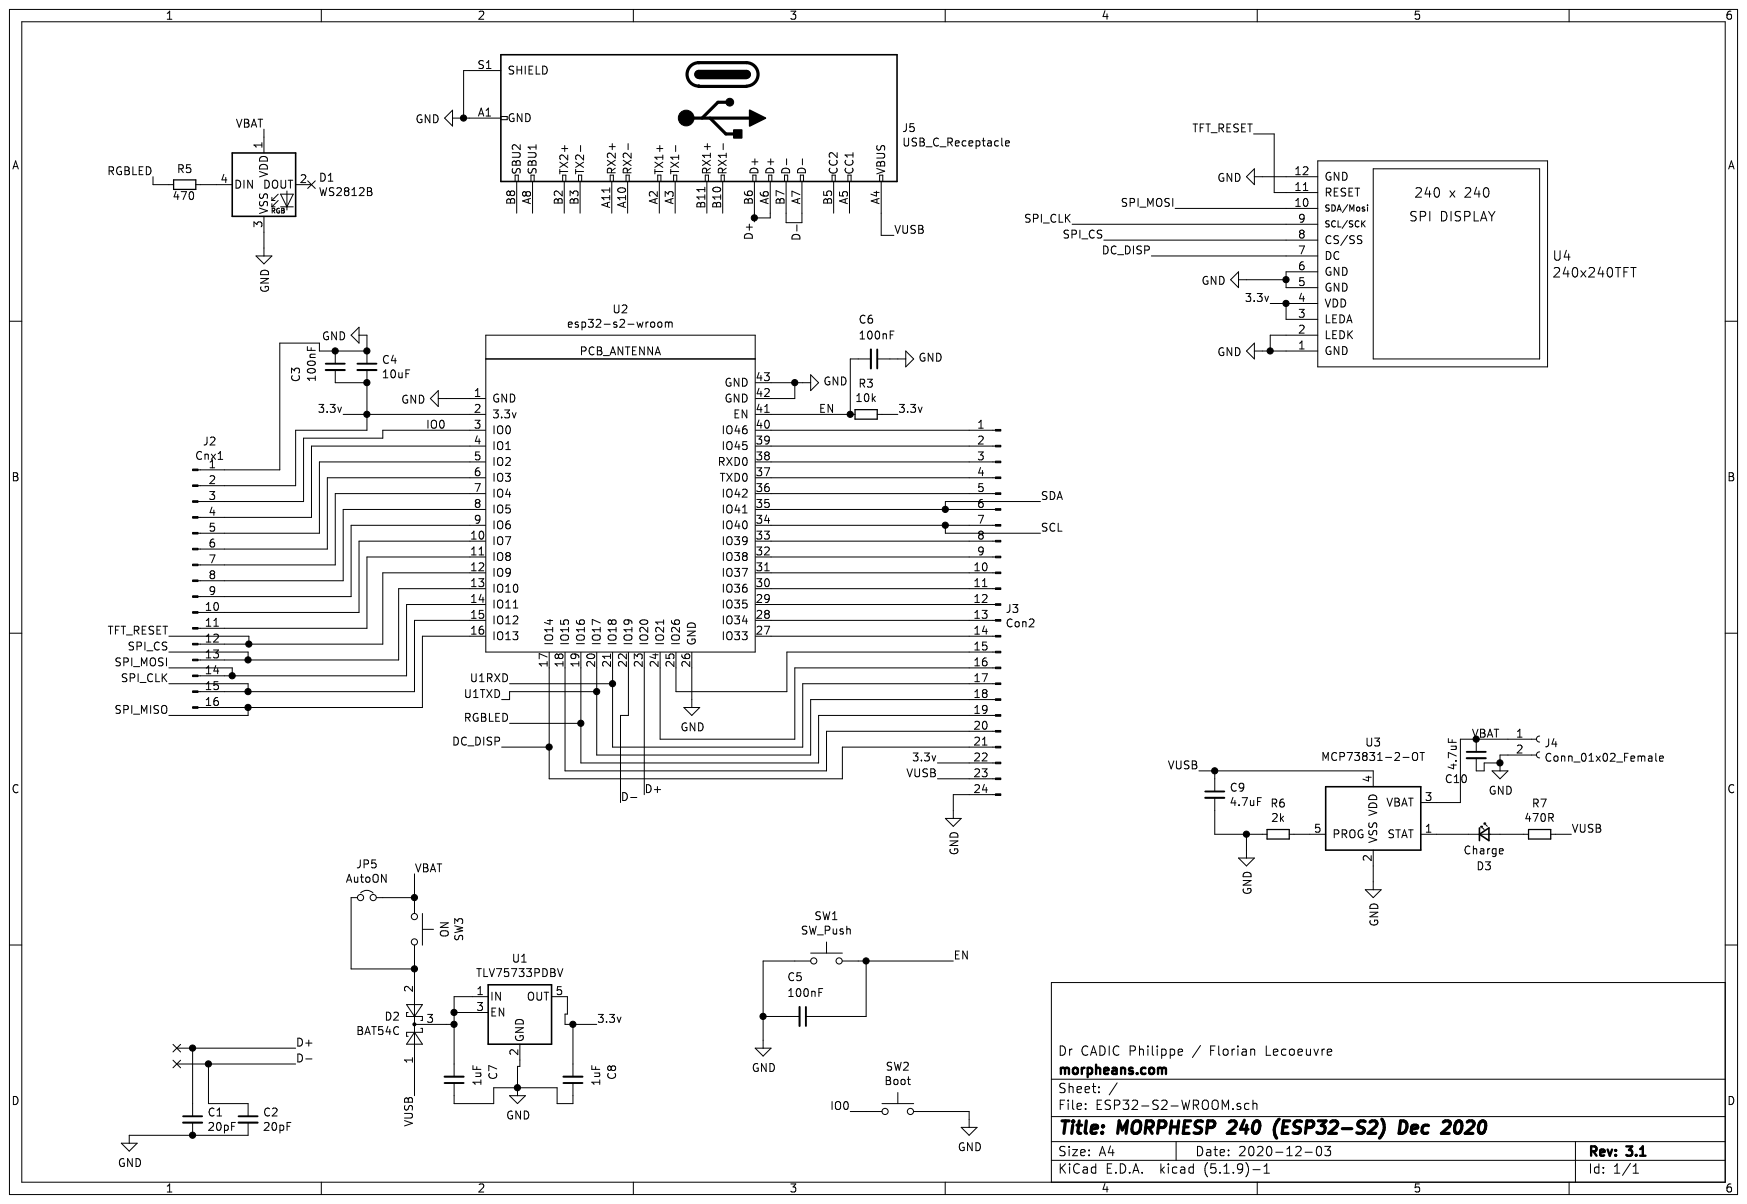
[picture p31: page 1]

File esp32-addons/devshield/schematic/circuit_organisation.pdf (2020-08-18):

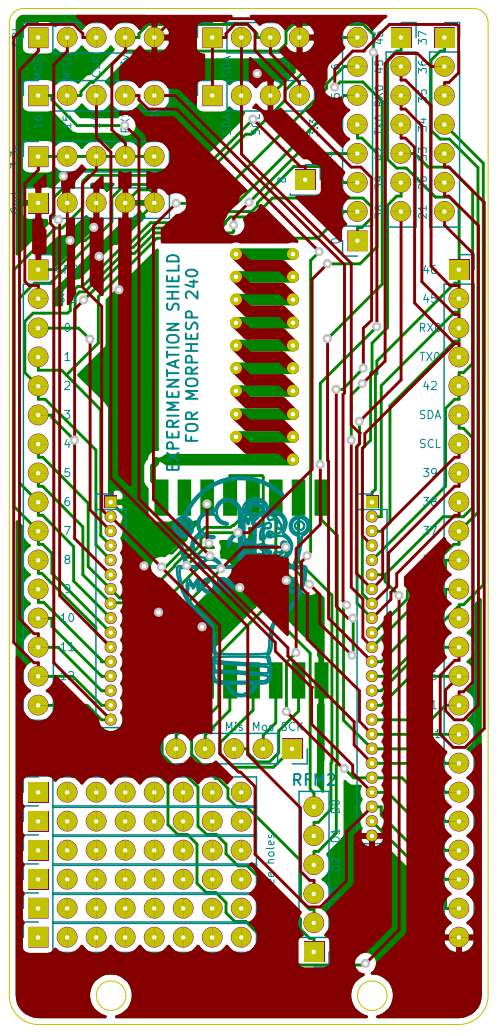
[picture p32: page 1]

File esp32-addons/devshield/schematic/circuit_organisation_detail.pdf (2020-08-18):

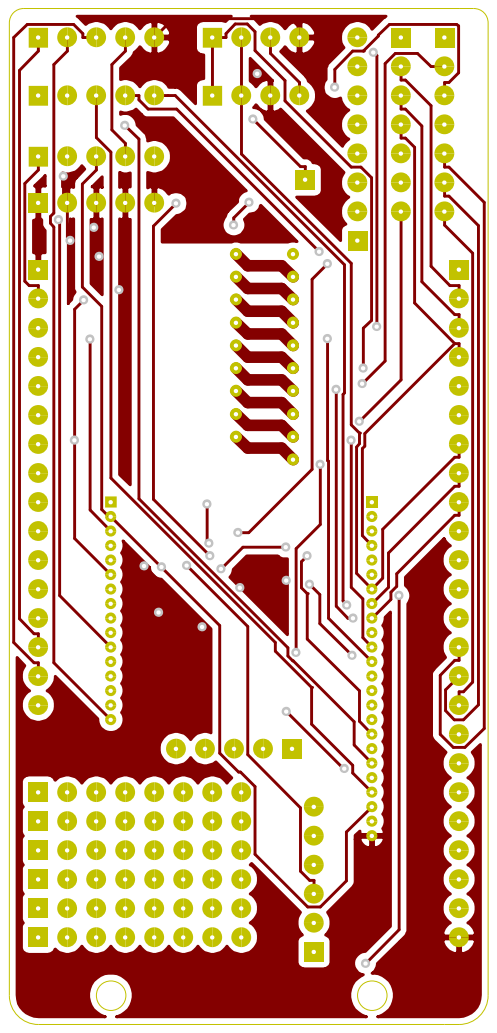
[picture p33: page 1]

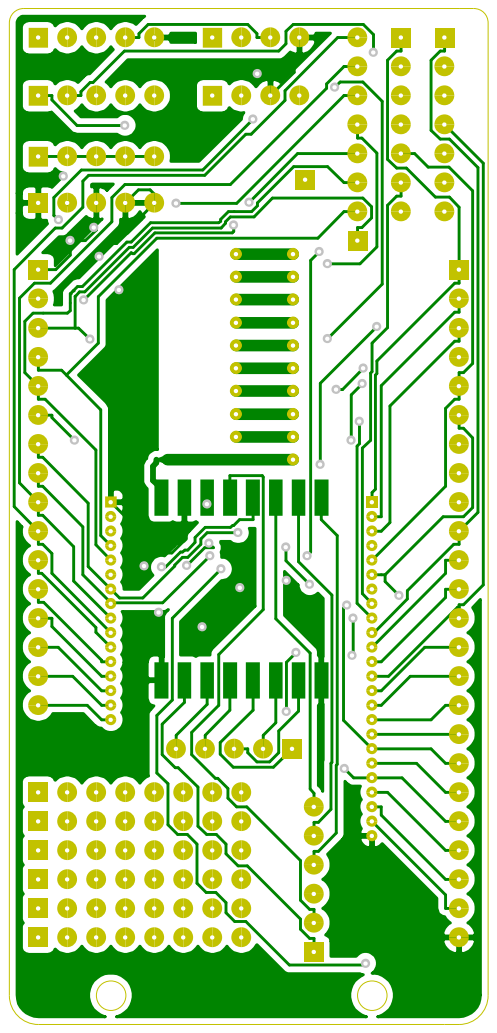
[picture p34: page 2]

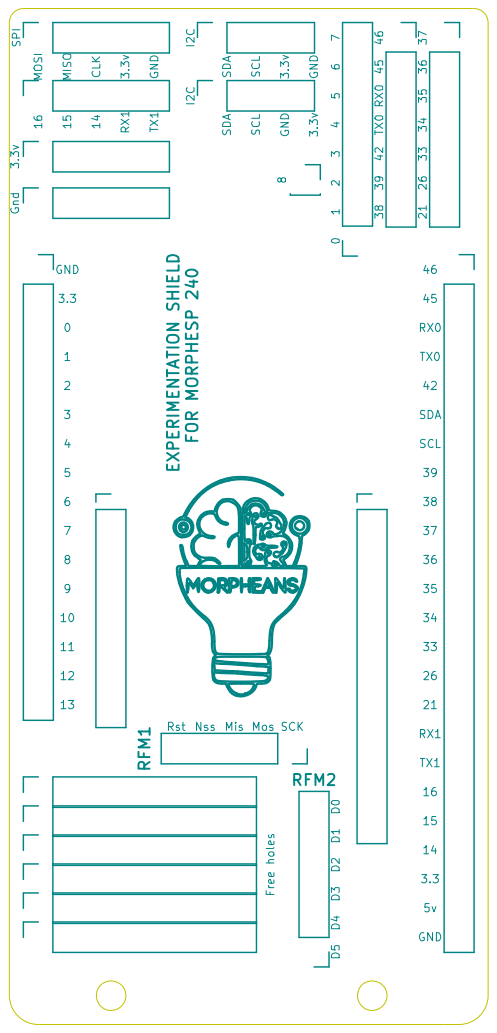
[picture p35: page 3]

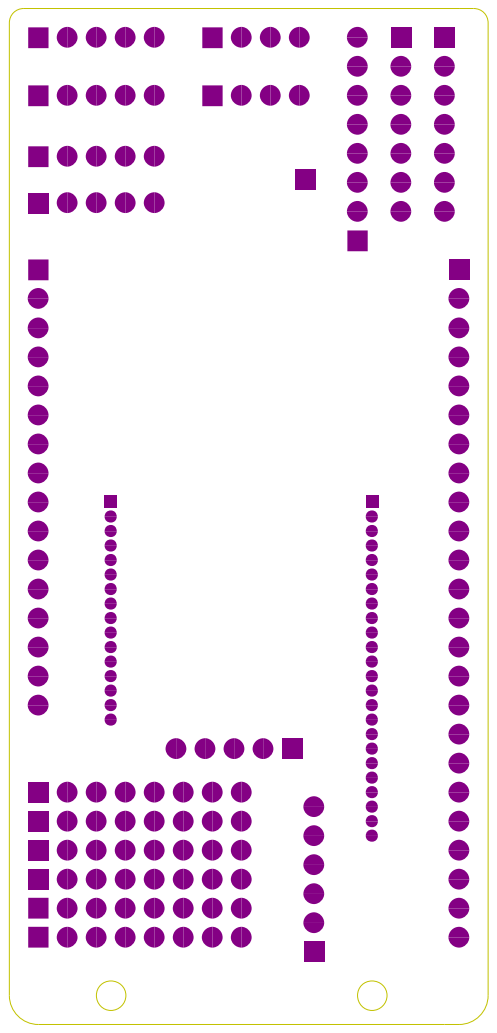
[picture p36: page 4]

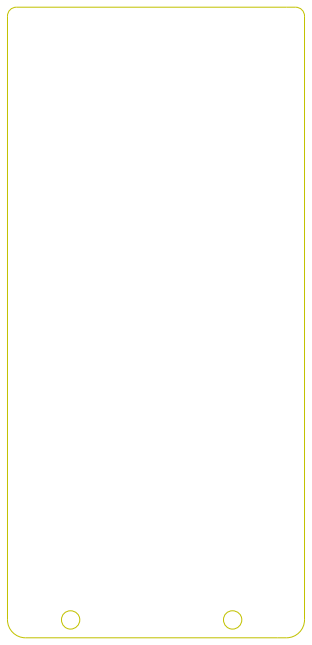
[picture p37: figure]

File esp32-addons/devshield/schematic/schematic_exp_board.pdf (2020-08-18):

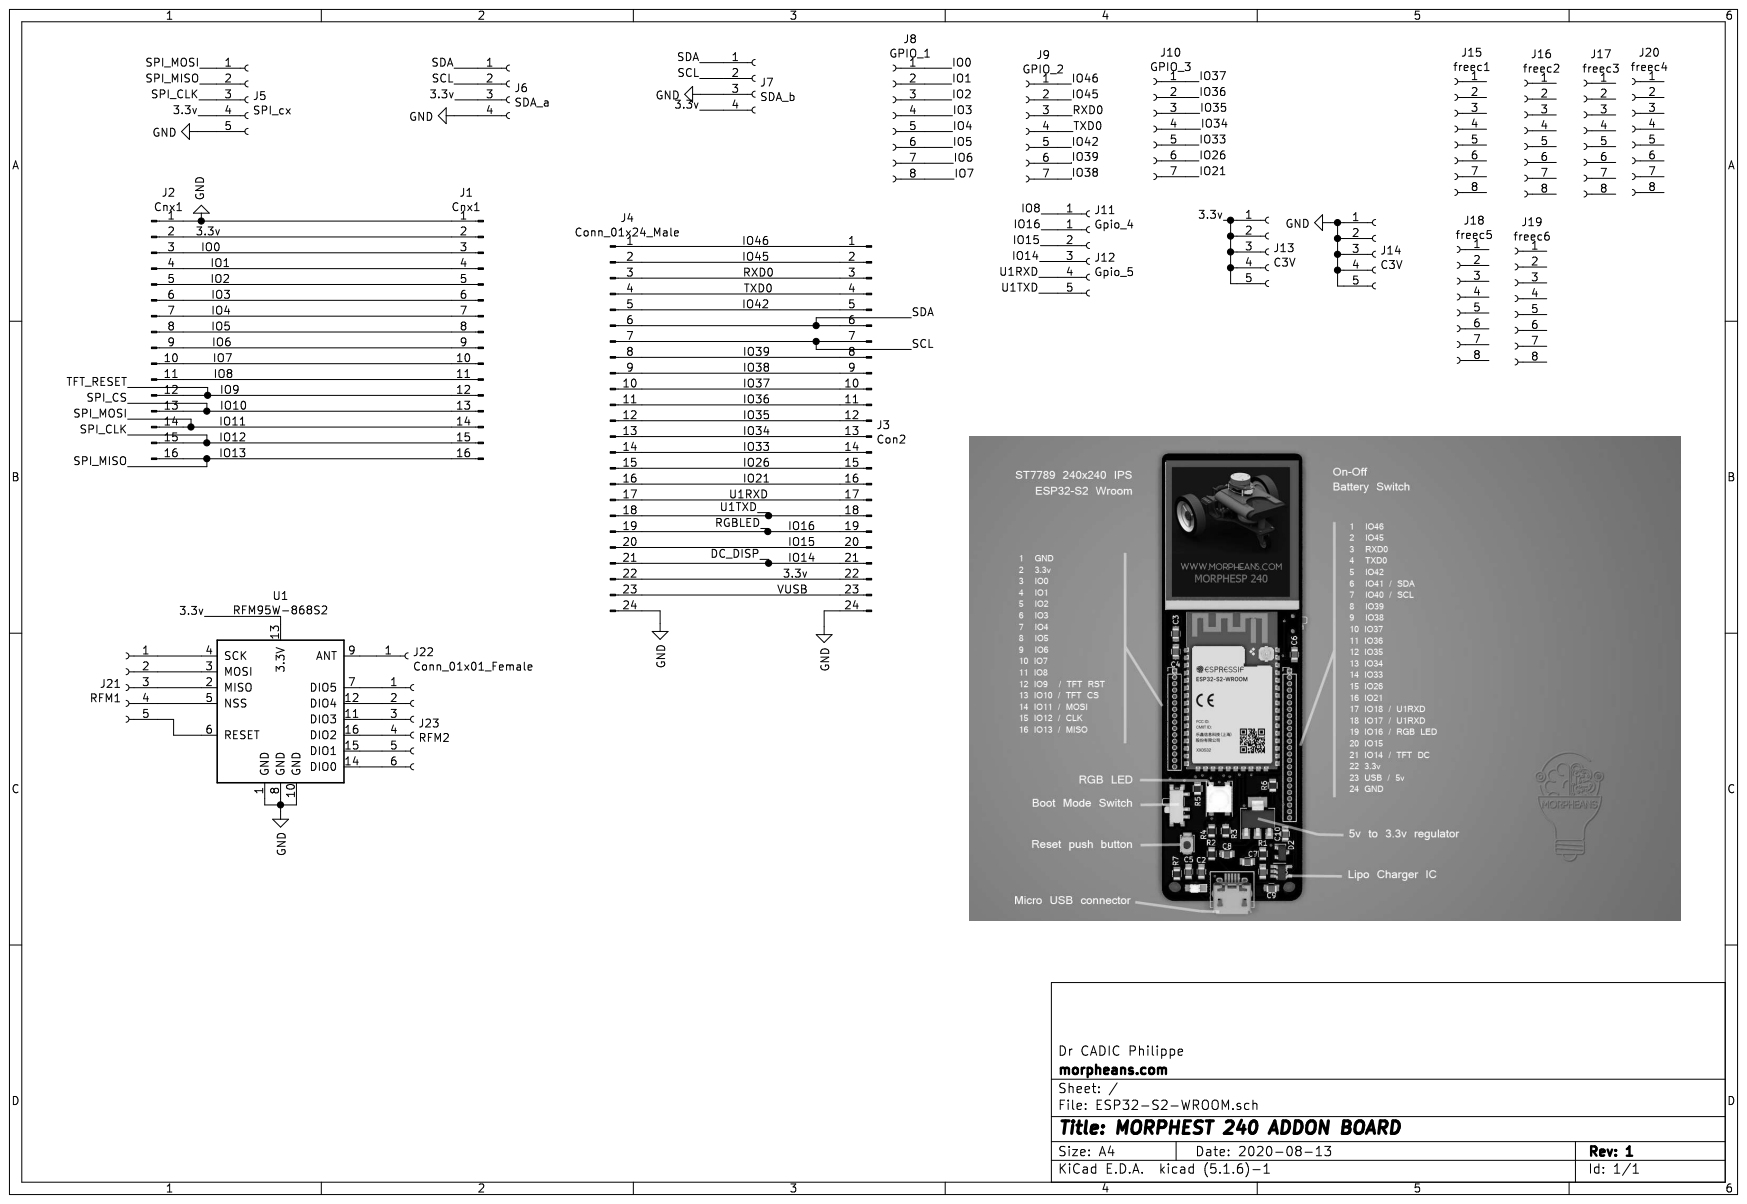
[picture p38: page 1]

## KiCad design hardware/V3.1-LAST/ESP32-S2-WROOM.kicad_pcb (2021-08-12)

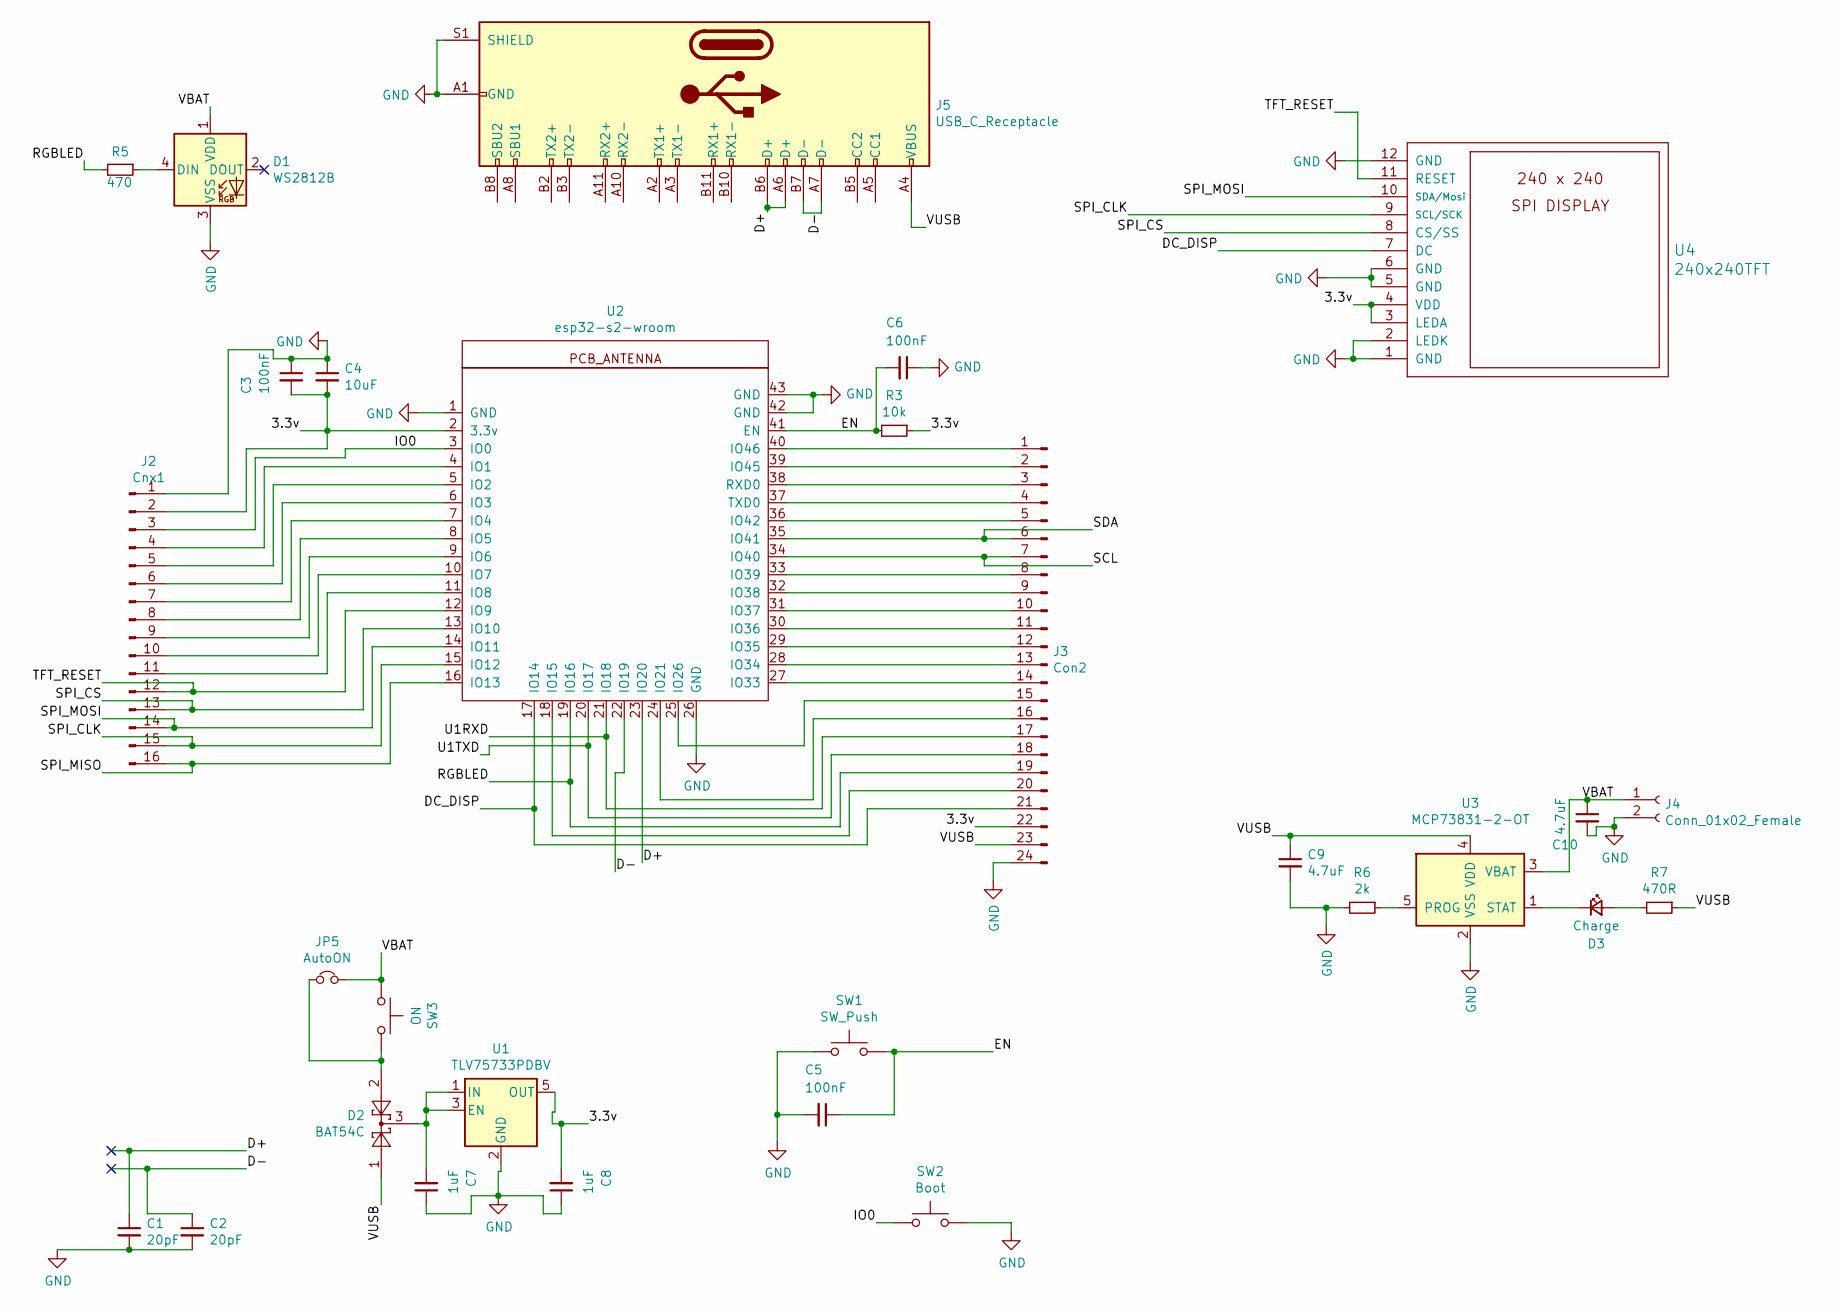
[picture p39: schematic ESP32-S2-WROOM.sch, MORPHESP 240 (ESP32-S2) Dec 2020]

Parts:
C1, C2: 20pF; C_0603
C3, C5, C6: 100nF; C_0603
C4: 10uF; C_0603
C7, C8: 1uF; C_0603
C9, C10: 4.7uF; C_0603
D1: WS2812B; LED_WS2812B-PLCC4
D2: BAT54C; SOT-23
D3: Charge; LED_0603
J2: Cnx1; Socket_Strip_Straight_1x16_Pitch1.27mm
J3: Con2; Socket_Strip_Straight_1x24_Pitch1.27mm
J4: Conn_01x02_Female; JST_PH_S2B-PH-SM4-TB_02x2.00mm_Angled
J5: USB_C_Receptacle; USB_C_Receptacle_GT-USB-7010
JP5: AutoON; JumperSmall
R3: 10k; R_0603
R5: 470; R_0603
R6: 2k; R_0603
R7: 470R; R_0603
SW1: SW_Push; SW_SPST_B3U-1000P
SW2: Boot; SW_SPST_B3U-1000P
SW3: ON; SW_SPDT_PCM12
U1: TLV75733PDBV; SOT-23-5
U2: esp32-s2-wroom; esp32-s2-wrooom
U3: MCP73831-2-OT; SOT-23-5
U4: 240x240TFT; 240240TFT

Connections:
/3.3v: C3.2, C4.2, C8.2, J2.2, J3.22, R3.1, U1.5 (OUT), U2.2 (3.3v), U4.3 (LEDA), U4.4 (VDD)
/D+: C1.1, J5.A6 (D+), J5.B6 (D+), U2.23 (IO20)
/D-: C2.1, J5.A7 (D-), J5.B7 (D-), U2.22 (IO19)
/DC_DISP: J3.21, U2.17 (IO14), U4.7 (DC)
/EN: C5.1, C6.2, R3.2, SW1.2, U2.41 (EN)
/IO0: J2.3, SW2.1, U2.3 (IO0)
/RGBLED: J3.19, R5.2, U2.19 (IO16)
/SCL: J3.7, U2.34 (IO40)
/SDA: J3.6, U2.35 (IO41)
/SPI_CLK: J2.15, U2.15 (IO12), U4.9 (SCL/SCK)
/SPI_CS: J2.13, U2.13 (IO10), U4.8 (CS/SS)
/SPI_MISO: J2.16, U2.16 (IO13)
/SPI_MOSI: J2.14, U2.14 (IO11), U4.10 (SDA/Mosi)
/TFT_RESET: J2.12, U2.12 (IO9), U4.11 (RESET)
/U1RXD: J3.17, U2.21 (IO18)
/U1TXD: J3.18, U2.20 (IO17)
/VBAT: C10.1, D1.1 (VDD), J4.1, JP5.2, SW3.1, U3.3 (VBAT)
/VUSB: C9.1, D2.1, J3.23, J5.A4 (VBUS), J5.A9 (VBUS), J5.B4 (VBUS), J5.B9 (VBUS), R7.1, U3.4 (VDD)
GND: C1.2, C2.2, C3.1, C4.1, C5.2, C6.1, C7.1, C8.1, C9.2, C10.2, D1.3 (VSS), J2.1, J3.24, J4.2, J5.A1 (GND), J5.A12 (GND), J5.B1 (GND), J5.B12 (GND), J5.S1 (SHIELD), R6.2, SW1.1, SW2.2, U1.2 (GND), U2.1 (GND), U2.26 (GND), U2.42 (GND), U2.43 (GND), U3.2 (VSS), U4.1 (GND), U4.2 (LEDK), U4.5 (GND), U4.6 (GND), U4.12 (GND)
unnamed: C7.2, D2.3, U1.1 (IN), U1.3 (EN)
unnamed: D1.4 (DIN), R5.1
unnamed: D2.2, JP5.1, SW3.2
unnamed: D3.1 (K), U3.1 (STAT)
unnamed: D3.2 (A), R7.2
unnamed: J2.4, U2.4 (IO1)
unnamed: J2.5, U2.5 (IO2)
unnamed: J2.6, U2.6 (IO3)
unnamed: J2.7, U2.7 (IO4)
unnamed: J2.8, U2.8 (IO5)
unnamed: J2.9, U2.9 (IO6)
unnamed: J2.10, U2.10 (IO7)
unnamed: J2.11, U2.11 (IO8)
unnamed: J3.1, U2.40 (IO46)
unnamed: J3.2, U2.39 (IO45)
unnamed: J3.3, U2.38 (RXD0)
unnamed: J3.4, U2.37 (TXD0)
unnamed: J3.5, U2.36 (IO42)
unnamed: J3.8, U2.33 (IO39)
unnamed: J3.9, U2.32 (IO38)
unnamed: J3.10, U2.31 (IO37)
unnamed: J3.11, U2.30 (IO36)
unnamed: J3.12, U2.29 (IO35)
unnamed: J3.13, U2.28 (IO34)
unnamed: J3.14, U2.27 (IO33)
unnamed: J3.15, U2.25 (IO26)
unnamed: J3.16, U2.24 (IO21)
unnamed: J3.20, U2.18 (IO15)
unnamed: R6.1, U3.5 (PROG)

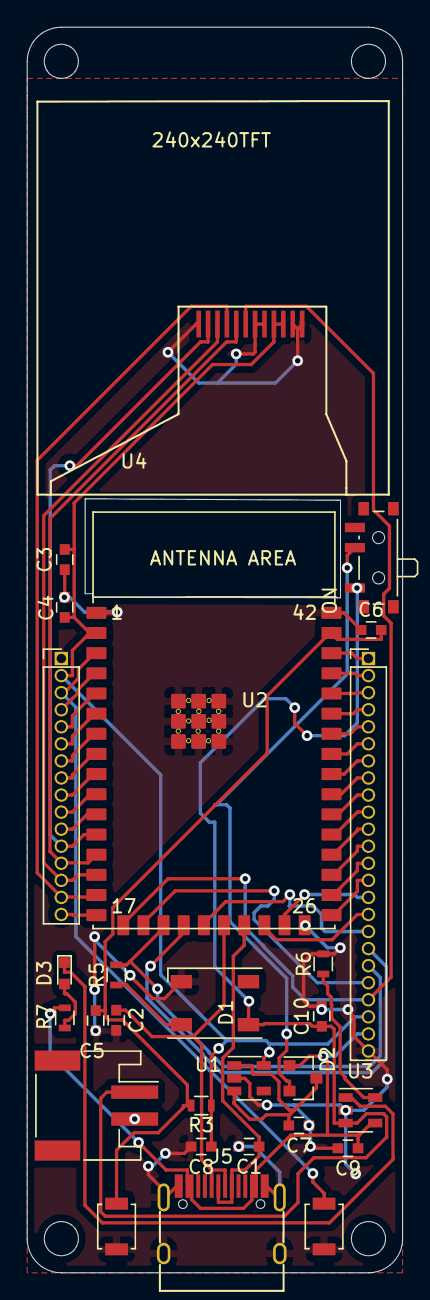
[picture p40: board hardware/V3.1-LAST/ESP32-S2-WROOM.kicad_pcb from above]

Board: 2 copper layers, 27.9 x 92.7 mm, 29 parts (1 on the bottom side), 48 nets.

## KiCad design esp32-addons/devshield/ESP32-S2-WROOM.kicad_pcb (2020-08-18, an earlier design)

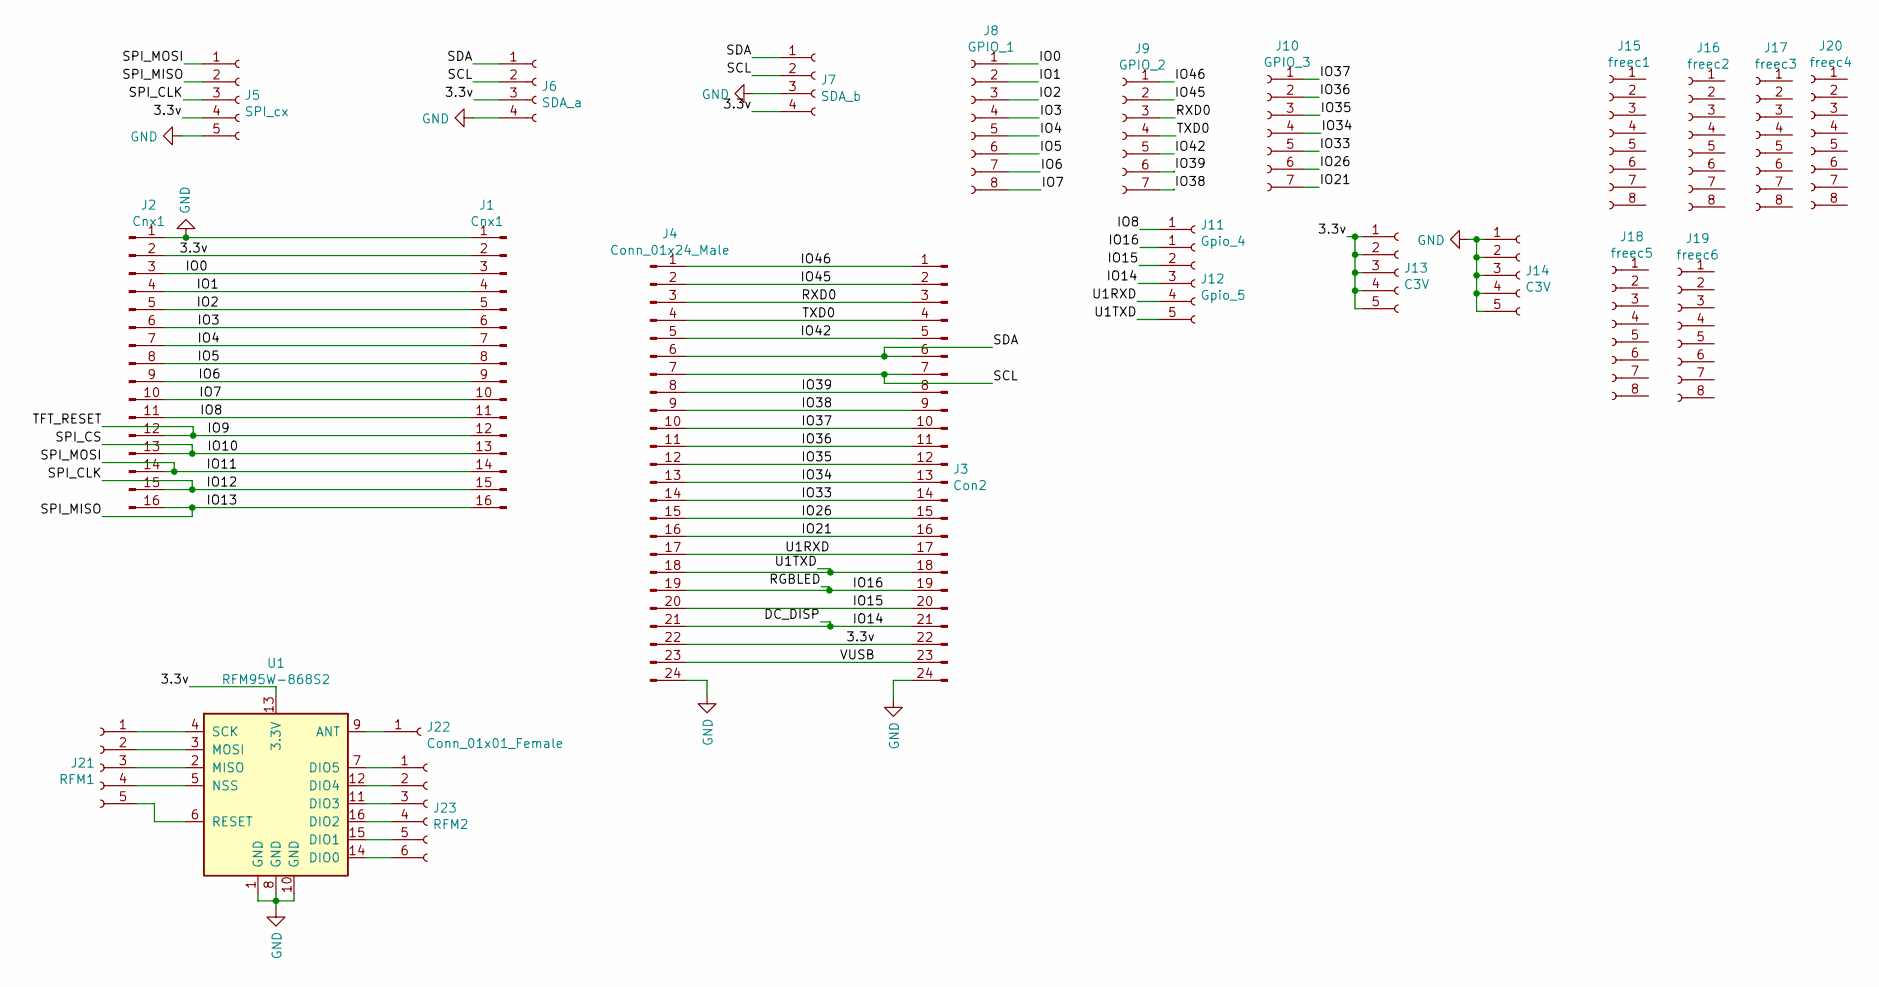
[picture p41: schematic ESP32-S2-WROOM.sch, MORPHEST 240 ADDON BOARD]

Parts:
J1: Cnx1; PinSocket_1x16_P2.54mm_Vertical
J2: Cnx1; Socket_Strip_Straight_1x16_Pitch1.27mm
J3: Con2; Socket_Strip_Straight_1x24_Pitch1.27mm
J4: Conn_01x24_Male; PinSocket_1x24_P2.54mm_Vertical
J5: SPI_cx; PinSocket_1x05_P2.54mm_Vertical
J6: SDA_a; PinSocket_1x04_P2.54mm_Vertical
J7: SDA_b; PinSocket_1x04_P2.54mm_Vertical
J8: GPIO_1; PinSocket_1x08_P2.54mm_Vertical
J9: GPIO_2; PinSocket_1x07_P2.54mm_Vertical
J10: GPIO_3; PinSocket_1x07_P2.54mm_Vertical
J11: Gpio_4; PinSocket_1x01_P2.54mm_Vertical
J12: Gpio_5; PinSocket_1x05_P2.54mm_Vertical
J13, J14: C3V; PinSocket_1x05_P2.54mm_Vertical
J15: freec1; PinSocket_1x08_P2.54mm_Vertical
J16: freec2; PinSocket_1x08_P2.54mm_Vertical
J17: freec3; PinSocket_1x08_P2.54mm_Vertical
J18: freec5; PinSocket_1x08_P2.54mm_Vertical
J19: freec6; PinSocket_1x08_P2.54mm_Vertical
J20: freec4; PinSocket_1x08_P2.54mm_Vertical
J21: RFM1; PinSocket_1x05_P2.54mm_Vertical
J22: Conn_01x01_Female; Texas_SWRA416_868MHz_915MHz
J23: RFM2; PinHeader_1x06_P2.54mm_Vertical
U1: RFM95W-868S2; RFM95W_long

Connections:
/3.3v: J1.2, J2.2, J3.22, J4.22, J5.4, J6.3, J7.4, J13.1, J13.2, J13.3, J13.4, J13.5, U1.13 (3.3V)
/DC_DISP: J3.21, J4.21, J12.3
/IO0: J1.3, J2.3, J8.1
/IO1: J1.4, J2.4, J8.2
/IO2: J1.5, J2.5, J8.3
/IO3: J1.6, J2.6, J8.4
/IO4: J1.7, J2.7, J8.5
/IO5: J1.8, J2.8, J8.6
/IO6: J1.9, J2.9, J8.7
/IO7: J1.10, J2.10, J8.8
/IO8: J1.11, J2.11, J11.1
/IO9: J1.12, J2.12
/IO10: J1.13, J2.13
/IO11: J1.14, J2.14, J5.1
/IO12: J1.15, J2.15, J5.3
/IO13: J1.16, J2.16, J5.2
/IO15: J3.20, J4.20, J12.2
/IO16: J3.19, J4.19, J12.1
/IO21: J3.16, J4.16, J10.7
/IO26: J3.15, J4.15, J10.6
/IO33: J3.14, J4.14, J10.5
/IO34: J3.13, J4.13, J10.4
/IO35: J3.12, J4.12, J10.3
/IO36: J3.11, J4.11, J10.2
/IO37: J3.10, J4.10, J10.1
/IO38: J3.9, J4.9, J9.7
/IO39: J3.8, J4.8, J9.6
/IO42: J3.5, J4.5, J9.5
/IO45: J3.2, J4.2, J9.2
/IO46: J3.1, J4.1, J9.1
/RXD0: J3.3, J4.3, J9.3
/SCL: J3.7, J4.7, J6.2, J7.2
/SDA: J3.6, J4.6, J6.1, J7.1
/TXD0: J3.4, J4.4, J9.4
/U1RXD: J3.17, J4.17, J12.4
/U1TXD: J3.18, J4.18, J12.5
/VUSB: J3.23, J4.23
GND: J1.1, J2.1, J3.24, J4.24, J5.5, J6.4, J7.3, J14.1, J14.2, J14.3, J14.4, J14.5, U1.1 (GND), U1.8 (GND), U1.10 (GND)
unnamed: J21.1, U1.4 (SCK)
unnamed: J21.2, U1.3 (MOSI)
unnamed: J21.3, U1.2 (MISO)
unnamed: J21.4, U1.5 (NSS)
unnamed: J21.5, U1.6 (RESET)
unnamed 43: J22.1, U1.9 (ANT); also elsewhere on the board
unnamed: J23.1, U1.7 (DIO5)
unnamed: J23.2, U1.12 (DIO4)
unnamed: J23.3, U1.11 (DIO3)
unnamed: J23.4, U1.16 (DIO2)
unnamed: J23.5, U1.15 (DIO1)
unnamed: J23.6, U1.14 (DIO0)

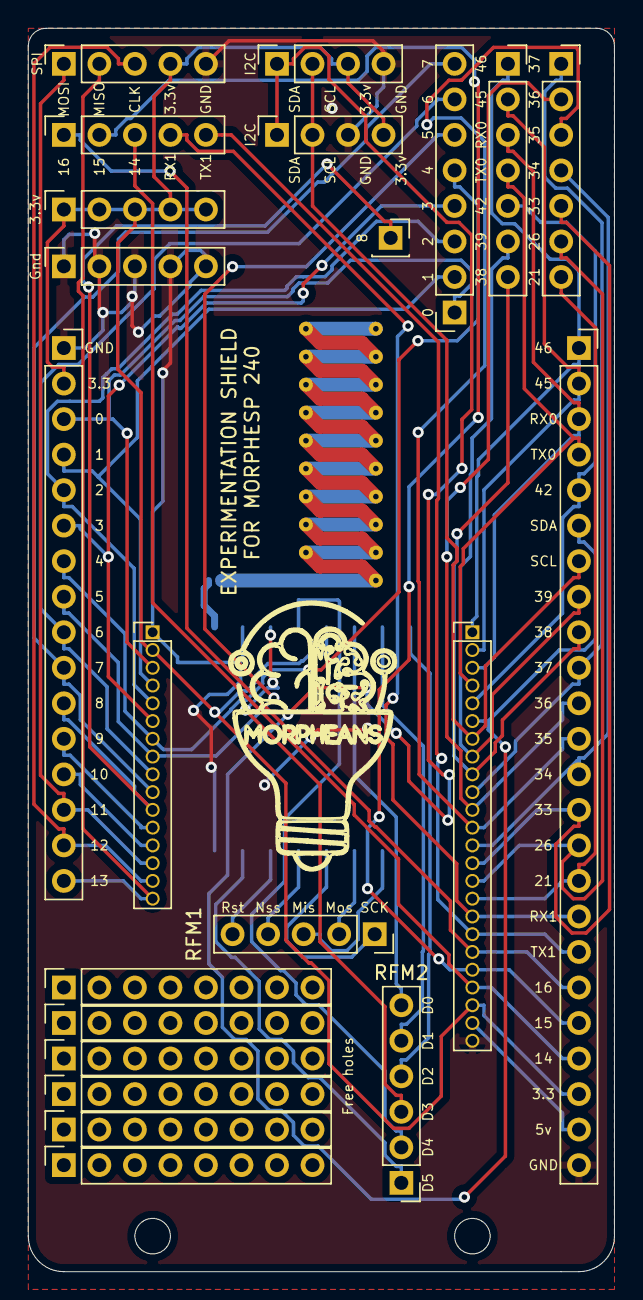
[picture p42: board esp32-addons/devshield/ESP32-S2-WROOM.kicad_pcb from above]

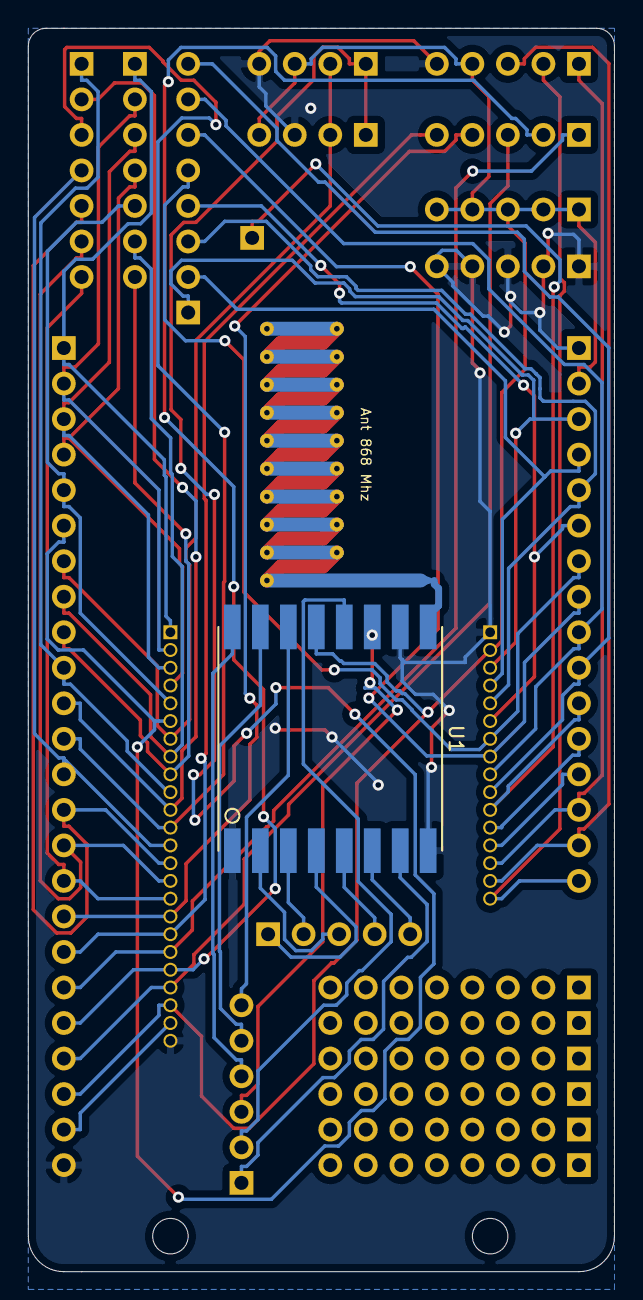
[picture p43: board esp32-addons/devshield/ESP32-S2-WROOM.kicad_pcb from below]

Board: 2 copper layers, 41.9 x 88.9 mm, 24 parts (2 on the bottom side), 50 nets.

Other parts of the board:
Ant 868 Mhz: Conn_01x01_Female; Texas_SWRA416_868MHz_915MHz

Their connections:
unnamed 43: Ant 868 Mhz.1; also elsewhere on the board

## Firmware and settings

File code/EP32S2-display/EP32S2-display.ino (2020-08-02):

/***************************************************
  This is a library for the ST7789 IPS SPI display.

  Originally written by Limor Fried/Ladyada for 
  Adafruit Industries.

  Modified by Ananev Ilia
 ****************************************************/

#include <Adafruit_GFX.h>    // Core graphics library by Adafruit
#include <Arduino_ST7789.h> // Hardware-specific library for ST7789 (with or without CS pin)
#include <SPI.h>

#define TFT_DC    14
#define TFT_RST   9 
#define TFT_CS    10 // only for displays with CS pin
#define TFT_MOSI  11   // for hardware SPI data pin (all of available pins)
#define TFT_SCLK  12   // for hardware SPI sclk pin (all of available pins)

//You can use different type of hardware initialization
//using hardware SPI (11, 13 on UNO; 51, 52 on MEGA; ICSP-4, ICSP-3 on DUE and etc)
//Arduino_ST7789 tft = Arduino_ST7789(TFT_DC, TFT_RST); //for display without CS pin
//Arduino_ST7789 tft = Arduino_ST7789(TFT_DC, TFT_RST, TFT_CS); //for display with CS pin
//or you can use software SPI on all available pins (slow)
//Arduino_ST7789 tft = Arduino_ST7789(TFT_DC, TFT_RST, TFT_MOSI, TFT_SCLK); //for display without CS pin
Arduino_ST7789 tft = Arduino_ST7789(TFT_DC, TFT_RST, TFT_MOSI, TFT_SCLK, TFT_CS); //for display with CS pin
//Arduino_ST7789 tft = Arduino_ST7789(-1, TFT_RST, TFT_MOSI, TFT_SCLK, TFT_CS); //for display with CS pin and DC via 9bit SPI


float p = 3.1415926;

void setup(void) {
  Serial.begin(115200);
  Serial.print("Hello! ST7789 TFT Test");

  tft.init(240, 240);   // initialize a ST7789 chip, 240x240 pixels

  Serial.println("Initialized");

  uint16_t time = millis();
  tft.fillScreen(BLACK);
  time = millis() - time;

  Serial.println(time, DEC);
  delay(500);

 

  // tft print function
  tftPrintTest();
  delay(4000);

  // a single pixel
  tft.drawPixel(tft.width()/2, tft.height()/2, GREEN);
  delay(500);

  // line draw test
  testlines(YELLOW);
  delay(500);

  // optimized lines
  testfastlines(RED, BLUE);
  delay(500);

  testdrawrects(GREEN);
  delay(500);

  testfillrects(YELLOW, MAGENTA);
  delay(500);

  tft.fillScreen(BLACK);
  testfillcircles(10, BLUE);
  testdrawcircles(10, WHITE);
  delay(500);

  testroundrects();
  delay(500);

  testtriangles();
  delay(500);

  mediabuttons();
  delay(500);

  Serial.println("done");
  delay(1000);
}

void loop() {
  tft.invertDisplay(true);
  delay(500);
  tft.invertDisplay(false);
  delay(500);
}

void testlines(uint16_t color) {
  tft.fillScreen(BLACK);
  for (int16_t x=0; x < tft.width(); x+=6) {
    tft.drawLine(0, 0, x, tft.height()-1, color);
  }
  for (int16_t y=0; y < tft.height(); y+=6) {
    tft.drawLine(0, 0, tft.width()-1, y, color);
  }

  tft.fillScreen(BLACK);
  for (int16_t x=0; x < tft.width(); x+=6) {
    tft.drawLine(tft.width()-1, 0, x, tft.height()-1, color);
  }
  for (int16_t y=0; y < tft.height(); y+=6) {
    tft.drawLine(tft.width()-1, 0, 0, y, color);
  }

  tft.fillScreen(BLACK);
  for (int16_t x=0; x < tft.width(); x+=6) {
    tft.drawLine(0, tft.height()-1, x, 0, color);
  }
  for (int16_t y=0; y < tft.height(); y+=6) {
    tft.drawLine(0, tft.height()-1, tft.width()-1, y, color);
  }

  tft.fillScreen(BLACK);
  for (int16_t x=0; x < tft.width(); x+=6) {
    tft.drawLine(tft.width()-1, tft.height()-1, x, 0, color);
  }
  for (int16_t y=0; y < tft.height(); y+=6) {
    tft.drawLine(tft.width()-1, tft.height()-1, 0, y, color);
  }
}

void testdrawtext(char *text, uint16_t color) {
  tft.setCursor(0, 0);
  tft.setTextColor(color);
  tft.setTextWrap(true);
  tft.print(text);
}

void testfastlines(uint16_t color1, uint16_t color2) {
  tft.fillScreen(BLACK);
  for (int16_t y=0; y < tft.height(); y+=5) {
    tft.drawFastHLine(0, y, tft.width(), color1);
  }
  for (int16_t x=0; x < tft.width(); x+=5) {
    tft.drawFastVLine(x, 0, tft.height(), color2);
  }
}

void testdrawrects(uint16_t color) {
  tft.fillScreen(BLACK);
  for (int16_t x=0; x < tft.width(); x+=6) {
    tft.drawRect(tft.width()/2 -x/2, tft.height()/2 -x/2 , x, x, color);
  }
}

void testfillrects(uint16_t color1, uint16_t color2) {
  tft.fillScreen(BLACK);
  for (int16_t x=tft.width()-1; x > 6; x-=6) {
    tft.fillRect(tft.width()/2 -x/2, tft.height()/2 -x/2 , x, x, color1);
    tft.drawRect(tft.width()/2 -x/2, tft.height()/2 -x/2 , x, x, color2);
  }
}

void testfillcircles(uint8_t radius, uint16_t color) {
  for (int16_t x=radius; x < tft.width(); x+=radius*2) {
    for (int16_t y=radius; y < tft.height(); y+=radius*2) {
      tft.fillCircle(x, y, radius, color);
    }
  }
}

void testdrawcircles(uint8_t radius, uint16_t color) {
  for (int16_t x=0; x < tft.width()+radius; x+=radius*2) {
    for (int16_t y=0; y < tft.height()+radius; y+=radius*2) {
      tft.drawCircle(x, y, radius, color);
    }
  }
}

void testtriangles() {
  tft.fillScreen(BLACK);
  int color = 0xF800;
  int t;
  int w = tft.width()/2;
  int x = tft.height()-1;
  int y = 0;
  int z = tft.width();
  for(t = 0 ; t <= 15; t++) {
    tft.drawTriangle(w, y, y, x, z, x, color);
    x-=4;
    y+=4;
    z-=4;
    color+=100;
  }
}

void testroundrects() {
  tft.fillScreen(BLACK);
  int color = 100;
  int i;
  int t;
  for(t = 0 ; t <= 4; t+=1) {
    int x = 0;
    int y = 0;
    int w = tft.width()-2;
    int h = tft.height()-2;
    for(i = 0 ; i <= 16; i+=1) {
      tft.drawRoundRect(x, y, w, h, 5, color);
      x+=2;
      y+=3;
      w-=4;
      h-=6;
      color+=1100;
    }
    color+=100;
  }
}

void tftPrintTest() {
  tft.setTextWrap(false);
  tft.fillScreen(BLACK);
  tft.setCursor(0, 30);
  tft.setTextColor(RED);
  tft.setTextSize(1);
  tft.println("Hello World!");
  tft.setTextColor(YELLOW);
  tft.setTextSize(2);
  tft.println("Hello World!");
  tft.setTextColor(GREEN);
  tft.setTextSize(3);
  tft.println("Hello World!");
  tft.setTextColor(BLUE);
  tft.setTextSize(4);
  tft.print(1234.567);
  delay(1500);
  tft.setCursor(0, 0);
  tft.fillScreen(BLACK);
  tft.setTextColor(WHITE);
  tft.setTextSize(0);
  tft.println("Hello World!");
  tft.setTextSize(1);
  tft.setTextColor(GREEN);
  tft.print(p, 6);
  tft.println(" Want pi?");
  tft.println(" ");
  tft.print(8675309, HEX); // print 8,675,309 out in HEX!
  tft.println(" Print HEX!");
  tft.println(" ");
  tft.setTextColor(WHITE);
  tft.println("Sketch has been");
  tft.println("running for: ");
  tft.setTextColor(MAGENTA);
  tft.print(millis() / 1000);
  tft.setTextColor(WHITE);
  tft.print(" seconds.");
}

void mediabuttons() {
  // play
  tft.fillScreen(BLACK);
  tft.fillRoundRect(25, 10, 78, 60, 8, WHITE);
  tft.fillTriangle(42, 20, 42, 60, 90, 40, RED);
  delay(500);
  // pause
  tft.fillRoundRect(25, 90, 78, 60, 8, WHITE);
  tft.fillRoundRect(39, 98, 20, 45, 5, GREEN);
  tft.fillRoundRect(69, 98, 20, 45, 5, GREEN);
  delay(500);
  // play color
  tft.fillTriangle(42, 20, 42, 60, 90, 40, BLUE);
  delay(50);
  // pause color
  tft.fillRoundRect(39, 98, 20, 45, 5, RED);
  tft.fillRoundRect(69, 98, 20, 45, 5, RED);
  // play color
  tft.fillTriangle(42, 20, 42, 60, 90, 40, GREEN);
}
